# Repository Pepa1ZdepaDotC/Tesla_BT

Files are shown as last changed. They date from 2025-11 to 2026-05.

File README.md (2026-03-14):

# Tesla 1128A repair and BT upgrade

[Schematic](https://github.com/Pepa1ZdepaDotC/Tesla_BT/blob/main/Tesla_rev_2/Tesla_sextant_BT.pdf)





[Interactive BOM](https://htmlpreview.github.io/?https://github.com/Pepa1ZdepaDotC/Tesla_a.s._BT/blob/main/BOM/ibom.html)

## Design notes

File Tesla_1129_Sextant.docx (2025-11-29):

Oprava rádia Tesla 1129 „Sextant“ – Hrubý

FM / AM Rádio není elektronkové, ale tranzistorové, je tam i gramofon. Celkem zachovalé, ovšem zaprášené a též chybí vidlice do zásuvky. Stav elektronických součástek jsem neprověřil, ale na první pohled vypadají v pořádku.

Opravy rádia:

- Výměna a vylepšení feritové (pásek) antény.
- Výměna reproduktoru.
- Oprava / výměna dalších nefunkčních součástek.

Vylepšení funkce:

- NFC čip pro zapnutí rádia mobilem, třeba i bezdrátové nabíjení.
- Bluetooth nebo Wifi připojení.
- Přední panel nastavení rádia.
- Další funkce dle konzultace.

Fotodokumentace:

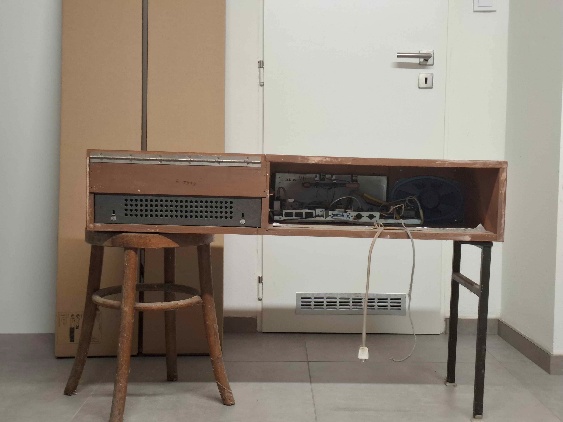
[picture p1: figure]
Obsah obrázku klavír, zeď, interiér, nábytek Popis byl vytvořen automaticky
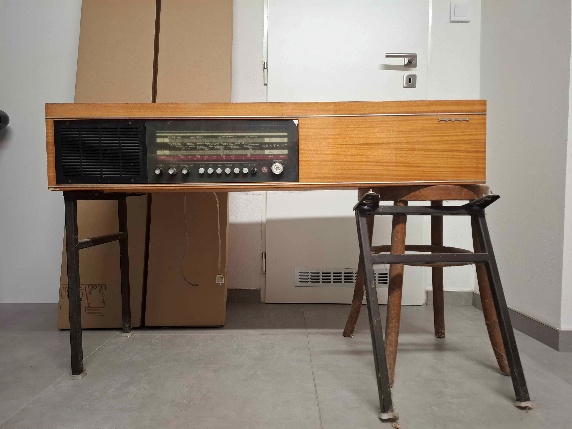
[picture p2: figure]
Obsah obrázku interiér, nábytek, zeď, klavír Popis byl vytvořen automaticky
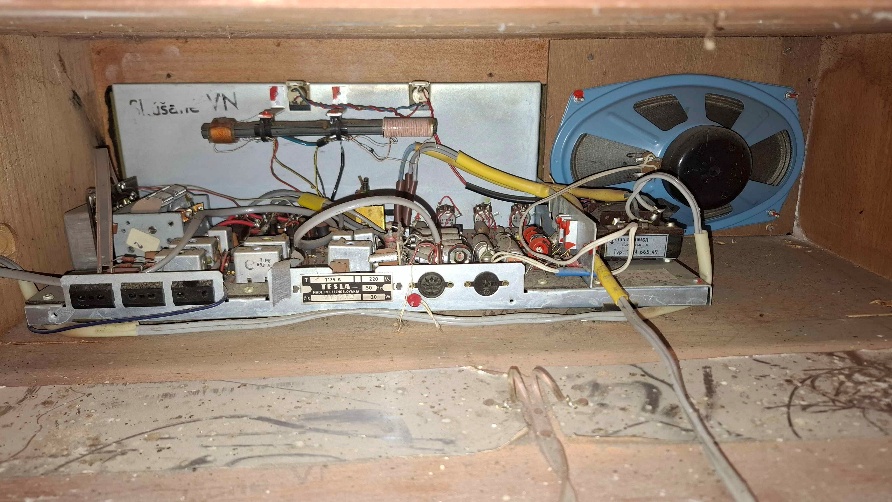
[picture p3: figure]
Obsah obrázku Elektrické vedení, Elektronické inženýrství, obvod, kabel Popis byl vytvořen automaticky

Související odkazy + Technická dokumentace:

https://www.oldradio.cz/ts1129.htm

https://www.oldradio.cz/kottek4/ek1129-30a.pdf

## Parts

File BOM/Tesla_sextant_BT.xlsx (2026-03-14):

Reference | Value | Footprint | Datasheet | Qty | Part_num | DNP | Exclude from BOM | Need | TME | Mouser
C1,C9,C14,C21,C27,C28,C29,C30,C37,C38 | 100nF | Capacitor_SMD:C_0805_2012Metric | ~ | 10
C2,C3,C4,C5,C10,C12,C13,C17,C22,C25,C26 | 10uF | Capacitor_SMD:C_0805_2012Metric | ~ | 11
C6,C7 | 2.2nF | Capacitor_SMD:C_0805_2012Metric | ~ | 2 |  |  |  |  | CL10B222KB8NNNC
C8,C11 | 2.2uF | Capacitor_SMD:C_0805_2012Metric | ~ | 2 |  |  |  | x | CL21B225KAFNNNE
C15,C16 | 470nF | Capacitor_SMD:C_0805_2012Metric | ~ | 2
C23,C24 | 22uF | Capacitor_SMD:C_0805_2012Metric | ~ | 2 |  |  |  | x | CL21A226MAYNNNE
C31 | 5pF | Capacitor_SMD:C_0603_1608Metric | ~ | 1 |  |  |  | x | 06035A5R0CAT2A
C32 | 130pF | Capacitor_SMD:C_0603_1608Metric | ~ | 1 |  |  |  | x | CL10C121JB8NNNC
C33,C40,C42 | 100nF | Capacitor_SMD:C_0603_1608Metric | ~ | 3 |  |  |  | x | 0603B104K500CT
C34,C35 | TBD | Capacitor_SMD:C_0603_1608Metric | ~ | 2 |  |  |  | x
C39 | 44pF | Capacitor_SMD:C_0603_1608Metric | ~ | 1 |  |  |  | x | CC0603BRNPO9BNR47
C41 | TBD | Capacitor_SMD:C_0805_2012Metric | ~ | 1 |  | DNP
D1 | WE-TVS-824015043 | Package_TO_SOT_SMD:SOT-23-6 | https://www.we-online.com/components/products/datasheet/824015043.pdf | 1 |  |  |  | x |  | 824015043
D2 | SMAJ5.0CA | Diode_SMD:D_SMA | https://www.littelfuse.com/media?itemid=75e32973-b177-4ee3-a0ff-cedaf1abdb93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 | 1 |  |  |  | x |  | SMAJ5.0CA
D3,D4,D6 | B240 | Diode_SMD:D_SMB | http://www.jameco.com/Jameco/Products/ProdDS/1538777.pdf | 3 |  |  |  | x |  | B240
D5 | SMAJ36A | Diode_SMD:D_SMA | https://www.littelfuse.com/media?itemid=75e32973-b177-4ee3-a0ff-cedaf1abdb93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 | 1 |  |  |  | x |  | SMAJ36A
D7,D8 | SMAJ5.0A | Diode_SMD:D_SMA | https://www.littelfuse.com/media?itemid=75e32973-b177-4ee3-a0ff-cedaf1abdb93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 | 2 |  |  |  | x |  | SMAJ5.0A
J1,J3 | Conn_01x05 | Connector_PinSocket_2.00mm:PinSocket_1x05_P2.00mm_Vertical | ~ | 2 |  |  |  | x |  | 831-87-005-10-001101
J6 | USB_C_Receptacle_USB2.0_16P | Connector_USB:USB_C_Receptacle_GCT_USB4105-xx-A_16P_TopMnt_Horizontal | https://www.usb.org/sites/default/files/documents/usb_type-c.zip | 1 | USB4105-GF-A |  |  | x | USB4105-GF-A
K1 | G6EU | Relay_THT:Relay_SPDT_Omron_G6E | https://www.omron.com/ecb/products/pdf/en-g6e.pdf | 1 |  |  |  | x | G6EU-134P-US-5DC
L2 | 2.2uH | Inductor_SMD:L_12x12mm_H8mm | https://www.eaton.com/content/dam/eaton/products/electronic-components/resources/data-sheet/eaton-dr-high-power-density-high-efficiency-shielded-drum-core-pow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 | 1 | DR125-2R2-R |  |  | x | DR125-2R2-R
L3 | 1uH | Capacitor_SMD:C_0603_1608Metric_Pad1.08x0.95mm_HandSolder | ~ | 1 |  |  |  | x | MLZ1608A1R0WT
L4 | 40nH | Capacitor_SMD:C_0603_1608Metric_Pad1.08x0.95mm_HandSolder | ~ | 1 |  |  |  |  | LQW18AN39NG00D
L5 | TBD | Inductor_SMD:L_0603_1608Metric | ~ | 1
L6,L7 | MABAES0060 | Tesla_Library:SM-22 | https://cdn.macom.com/datasheets/MABAES0060.pdf | 2 |  |  |  | x |  | MABAES0060
L8 | 900nH | Inductor_SMD:L_0603_1608Metric | ~ | 1 |  |  |  | x | NL03JTCR82
Q1 | BC817 | Package_TO_SOT_SMD:SOT-23 | https://www.onsemi.com/pub/Collateral/BC818-D.pdf | 1
R1,R2,R3,R6,R7,R16 | 10K | Resistor_SMD:R_0805_2012Metric | ~ | 6
R8,R10 | 470 | Resistor_SMD:R_0805_2012Metric | ~ | 2 |  |  |  | x | ERJHP6D4700V
R9,R11 | 3.3K | Resistor_SMD:R_0805_2012Metric | ~ | 2
R12,R13 | TBD | Resistor_SMD:R_0805_2012Metric | ~ | 2 |  |  |  | x
R14 | 7.5K | Resistor_SMD:R_0805_2012Metric | ~ | 1
R15,R17 | 1K | Resistor_SMD:R_0805_2012Metric | ~ | 2
R19,R20 | 100K | Resistor_SMD:R_0805_2012Metric | ~ | 2
R22,R23 | 5.1K | Resistor_SMD:R_0805_2012Metric | ~ | 2
R25 | 120 | Resistor_SMD:R_0805_2012Metric | ~ | 1 |  |  |  | x | WR08X1200FTL
R26 | 820 | Resistor_SMD:R_0805_2012Metric | ~ | 1 |  |  |  | x | ERA6AEB821V
R27,R33,R34 | 75 | Resistor_SMD:R_0805_2012Metric | ~ | 3 |  |  |  | x | RC0805FR-0775RL
R28 | 100 | Resistor_SMD:R_0805_2012Metric | ~ | 1 |  |  |  | x | RCA0805100RFKEA
R30 | 50 | Resistor_SMD:R_0805_2012Metric | ~ | 1 |  |  |  | x | CRCW080549R9FKE
R31,R32 | 5K | Resistor_SMD:R_0805_2012Metric | ~ | 2
U1 | ESP32-C3-WROOM-02 | RF_Module:ESP32-C3-WROOM-02 | https://www.espressif.com/sites/default/files/documentation/esp32-c3-wroom-02_datasheet_en.pdf | 1 |  |  |  | x |  | ESP32-C3-WROOM-02-N4
U2 | PCM5102A | Package_SO:TSSOP-20_4.4x6.5mm_P0.65mm | https://www.ti.com/lit/ds/symlink/pcm5102a.pdf | 1 |  |  |  | x |  | PCM5102APWR
U3 | OPA2342 | Package_SO:SOIC-8_3.9x4.9mm_P1.27mm | https://www.ti.com/lit/gpn/opa2342 | 1 |  |  |  | x |  | OPA2342
U4 | TPA0211 | Package_SO:HVSSOP-8-1EP_3x3mm_P0.65mm_EP1.57x1.89mm_ThermalVias | https://www.ti.com/lit/gpn/tpa0211 | 1 |  |  |  | x |  | TPA0211DGN
U5 | USBLC6-2SC6 | Package_TO_SOT_SMD:SOT-23-6 | https://www.st.com/resource/en/datasheet/usblc6-2.pdf | 1 |  |  |  | x |  | USBLC6-2SC6
U6 | AP63203WU | Package_TO_SOT_SMD:TSOT-23-6 | https://www.diodes.com/assets/Datasheets/AP63200-AP63201-AP63203-AP63205.pdf | 1 |  |  |  | x |  | AP63203WU-7
U7 | LD1117STR | Package_TO_SOT_SMD:SOT-223 |  | 1 |  |  |  | x |  | LD1117STR
U8 | AD831 | Package_LCC:PLCC-20 | https://www.analog.com/en/products/ad831.html?doc=ad831.pdf | 1 |  |  |  | x |  | AD831
Y1 | OSC25M-3.3I/S5 | Oscillator:Oscillator_SMD_Fordahl_DFAS15-4Pin_5.0x3.2mm_HandSoldering | https://www.tme.eu/Document/7a0ceeaed569e73bfa5cc28fb0e463dd/YIC-S7.pdf | 1 |  |  |  | x | OSC25M-3.3I/S5
 |  |  |  |  |  |  |  |  | 20 | 15

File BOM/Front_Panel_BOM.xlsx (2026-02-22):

Reference | Qty | Value | DNP | Exclude from BOM | Exclude from Board | Footprint | Datasheet
C1,C2,C3,C4 | 4 | 470nF |  |  |  | Capacitor_SMD:C_0805_2012Metric | ~
C5,C6,C7 | 3 | 100nF |  |  |  | Capacitor_SMD:C_0805_2012Metric | ~
H1,H2,H3,H4 | 4 | MountingHole_Pad |  | Excluded from BOM |  | MountingHole:MountingHole_4.3mm_M4_DIN965_Pad_TopBottom | ~
J1 | 1 | Conn_01x05 |  |  |  | Connector_PinSocket_2.00mm:PinSocket_1x05_P2.00mm_Vertical | ~
J2 | 1 | Conn_01x05 | DNP |  |  | Connector_PinSocket_2.00mm:PinSocket_1x05_P2.00mm_Vertical | ~
Q1 | 1 | BC817 |  |  |  | Package_TO_SOT_SMD:SOT-23 | https://www.onsemi.com/pub/Collateral/BC818-D.pdf
R1 | 1 | 0R | DNP |  |  | Resistor_SMD:R_0805_2012Metric | ~
R2 | 1 | 1K |  |  |  | Resistor_SMD:R_0805_2012Metric | ~
R3,R4,R5,R6 | 4 | 10K |  |  |  | Resistor_SMD:R_0805_2012Metric | ~
SW1,SW2,SW3,SW4 | 4 | SW_Push |  |  |  | Button_Switch_THT:SW_PUSH-12mm_Wuerth-430476085716 | ~
TP1,TP2 | 2 | TestPoint |  |  |  | TestPoint:TestPoint_Pad_D3.0mm | ~
U1 | 1 | NHD-C0220BIZ |  |  |  | Display:NHD-C0220BiZ | http://www.newhavendisplay.com/specs/NHD-C0220BiZ-FSW-FBW-3V3M.pdf
U2 | 1 | MCP23008-xSO |  |  |  | Package_SO:SOIC-18W_7.5x11.6mm_P1.27mm | http://ww1.microchip.com/downloads/en/DeviceDoc/MCP23008-MCP23S08-Data-Sheet-20001919F.pdf

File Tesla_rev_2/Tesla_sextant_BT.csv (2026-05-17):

Reference | Value | Qty | Part_num
C1,C9,C21,C27,C28,C29,C30,C37,C38 | 100nF | 9
C2,C3,C4,C5,C10,C12,C13,C22,C25,C26 | 10uF | 10
C6,C7 | 2.2nF | 2
C8,C11 | 2.2uF | 2
C15,C16 | 470nF | 2
C23,C24 | 22uF | 2
C31,C34,C35 | 5pF | 3
C32 | 130pF | 1
C33,C40,C42 | 100nF | 3
C36 | 510pF | 1
C39 | 44pF | 1
C41 | TBD | 1
D1 | WE-TVS-824015043 | 1
D2 | SMAJ5.0CA | 1
D3,D4,D6 | B240 | 3
D5 | SMAJ36A | 1
D7,D8 | SMAJ5.0A | 2
J1,J3 | Conn_01x05 | 2
J6 | USB_C_Receptacle_USB2.0_16P | 1 | USB4105-GF-A
K1 | G5V-1 | 1
L2 | 2.2uH | 1 | DR125-2R2-R
L3 | 1uH | 1
L4 | 40nH | 1
L5 | 430nH | 1
L6,L7 | MABAES0060 | 2
L8 | 900nH | 1
Q1 | BC817 | 1
R1,R2,R3,R6,R7,R16 | 10K | 6
R8,R10 | 470 | 2
R9,R11 | 3.3K | 2
R12,R13 | TBD | 2
R15 | 1K | 1
R22,R23 | 5.1K | 2
R25 | 120 | 1
R26 | 820 | 1
R27,R33,R34 | 75 | 3
R28 | 100 | 1
R29 | 200 | 1
R30 | 50 | 1
R31,R32 | 5K | 2
U1 | ESP32-C3-WROOM-02 | 1
U2 | PCM5102A | 1
U4 | TPA0211 | 1
U5 | USBLC6-2SC6 | 1
U6 | AP63203WU | 1
U7 | LD1117STR | 1
U8 | AD831 | 1
Y1 | OSC25M-3.3I/S5 | 1
C1,C2,C3,C4 | 470nF | 4
C5,C6,C7 | 100nF | 3
J1 | Conn_01x05 | 1
J2 | Conn_01x05 | 1
Q1 | BC817 | 1
R1 | 0R | 1
R2 | 1K | 1
R3,R4,R5,R6 | 10K | 4
SW1,SW2,SW3,SW4 | SW_Push | 4
TP1,TP2 | TestPoint | 2
U1 | NHD-C0220BIZ | 1
U2 | MCP23008-xSO | 1

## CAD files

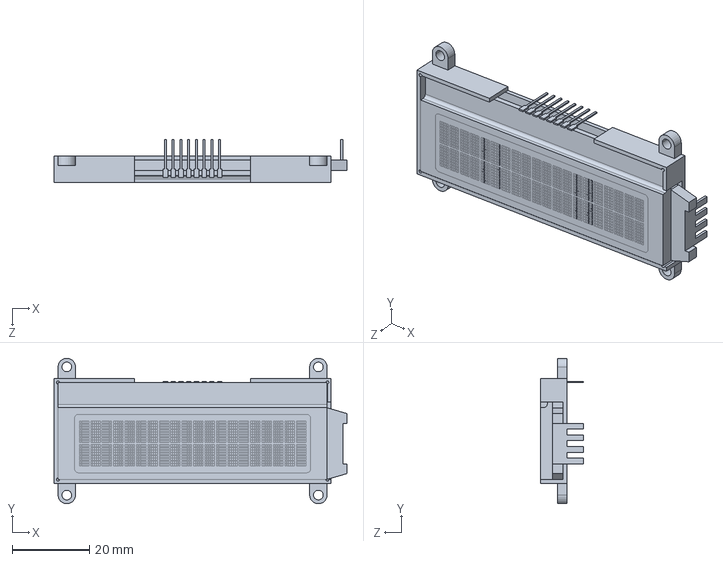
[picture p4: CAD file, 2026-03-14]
Front_Panel/verified_NHD-C0220BiZ-FSRGB-FBW-3VM.STEP
75.7 x 37.6 x 11.0 mm

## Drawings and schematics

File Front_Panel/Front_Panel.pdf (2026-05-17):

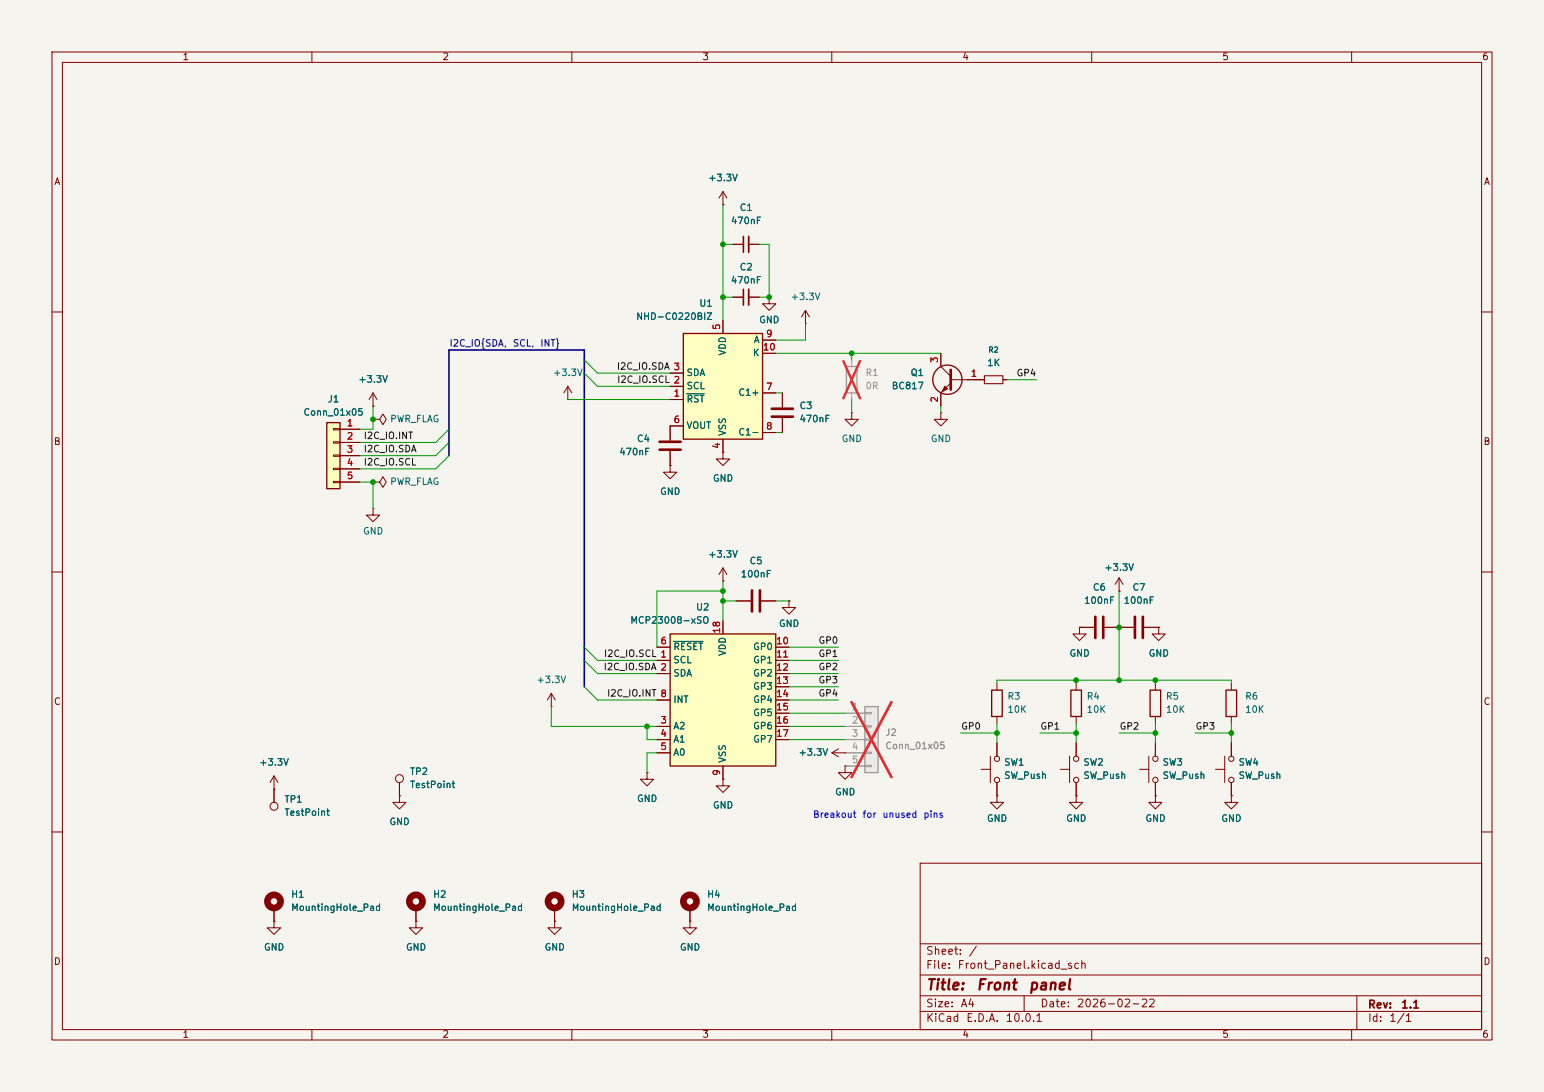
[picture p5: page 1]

Size: A4 | Rev: 1.1
KiCad E.D.A. 10.0.1 | Id: 1/1

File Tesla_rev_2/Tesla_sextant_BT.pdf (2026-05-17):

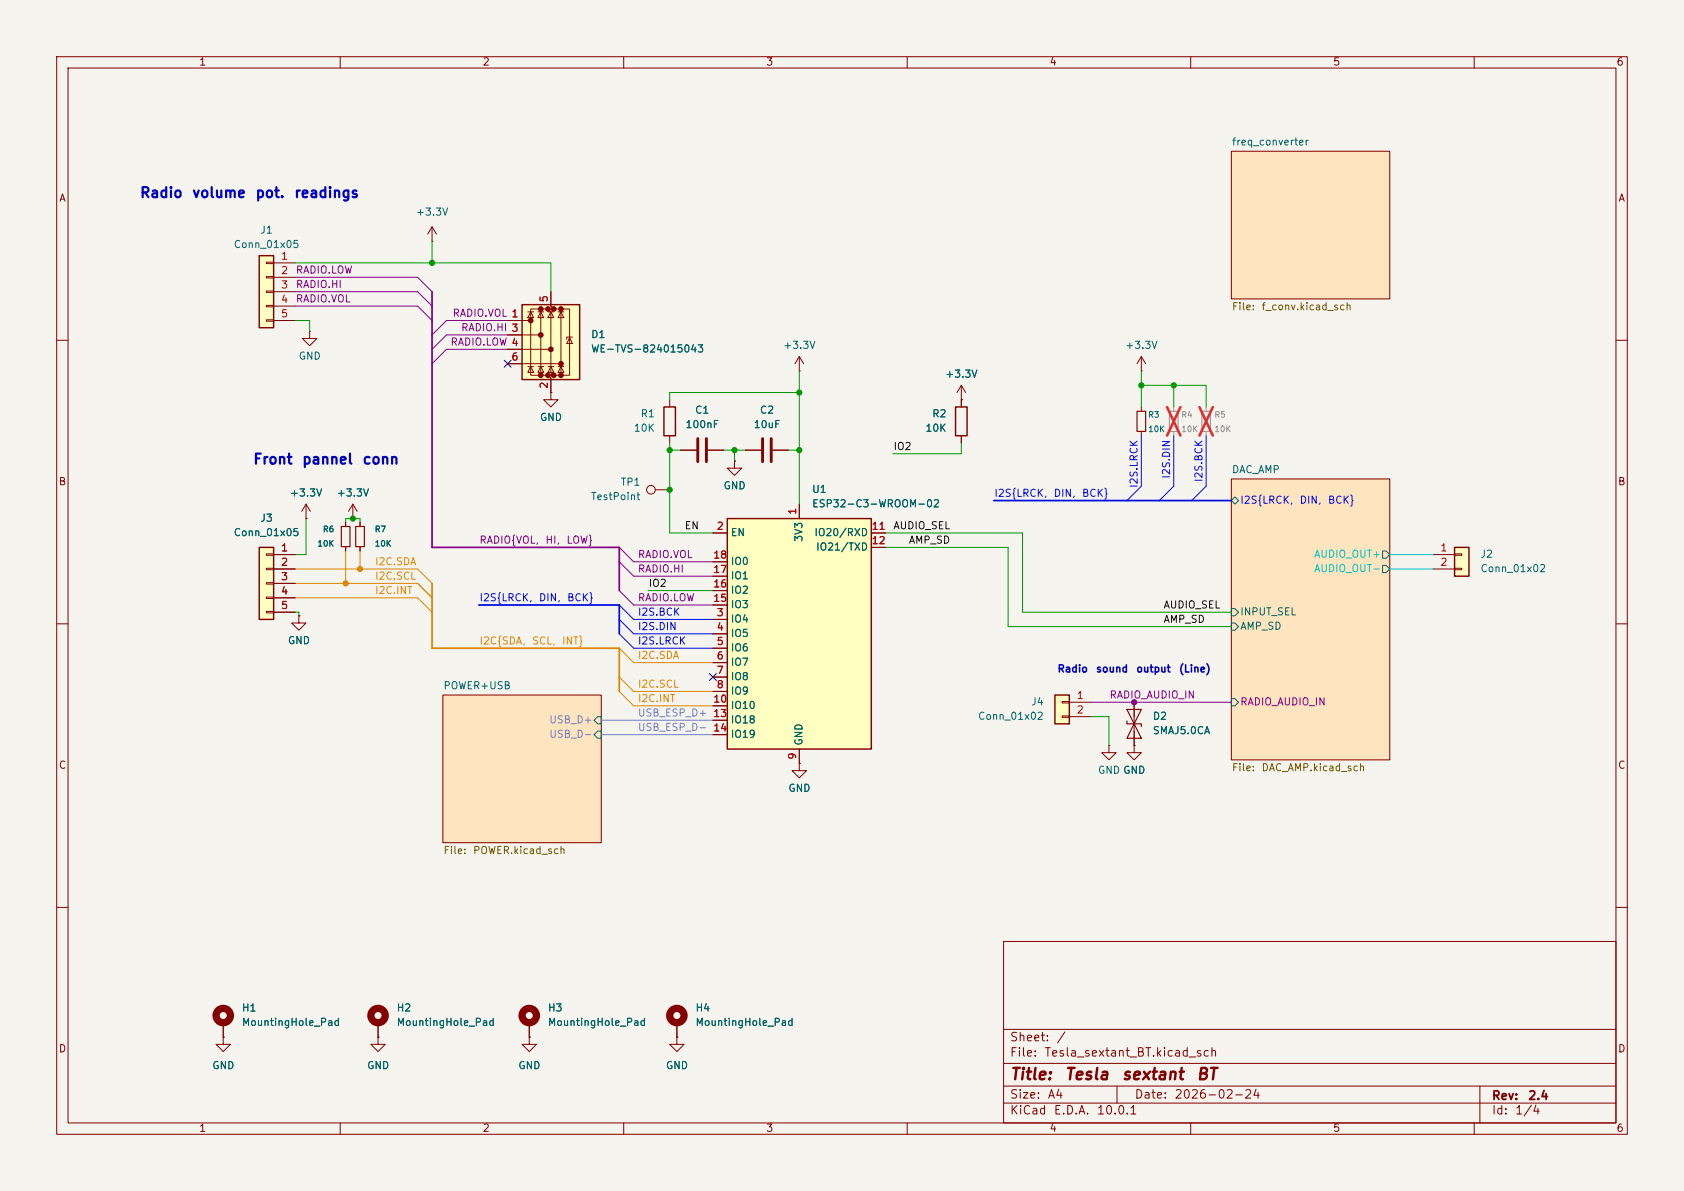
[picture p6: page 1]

I2S.BCK Front pannel conn Radio volume pot. readings

Radio sound output (Line) C2

Sheet: /
File: Tesla_sextant_BT.kicad_sch
Title: Tesla sextant BT

Size: A4 | Rev: 2.4
KiCad E.D.A. 10.0.1 | Id: 1/4

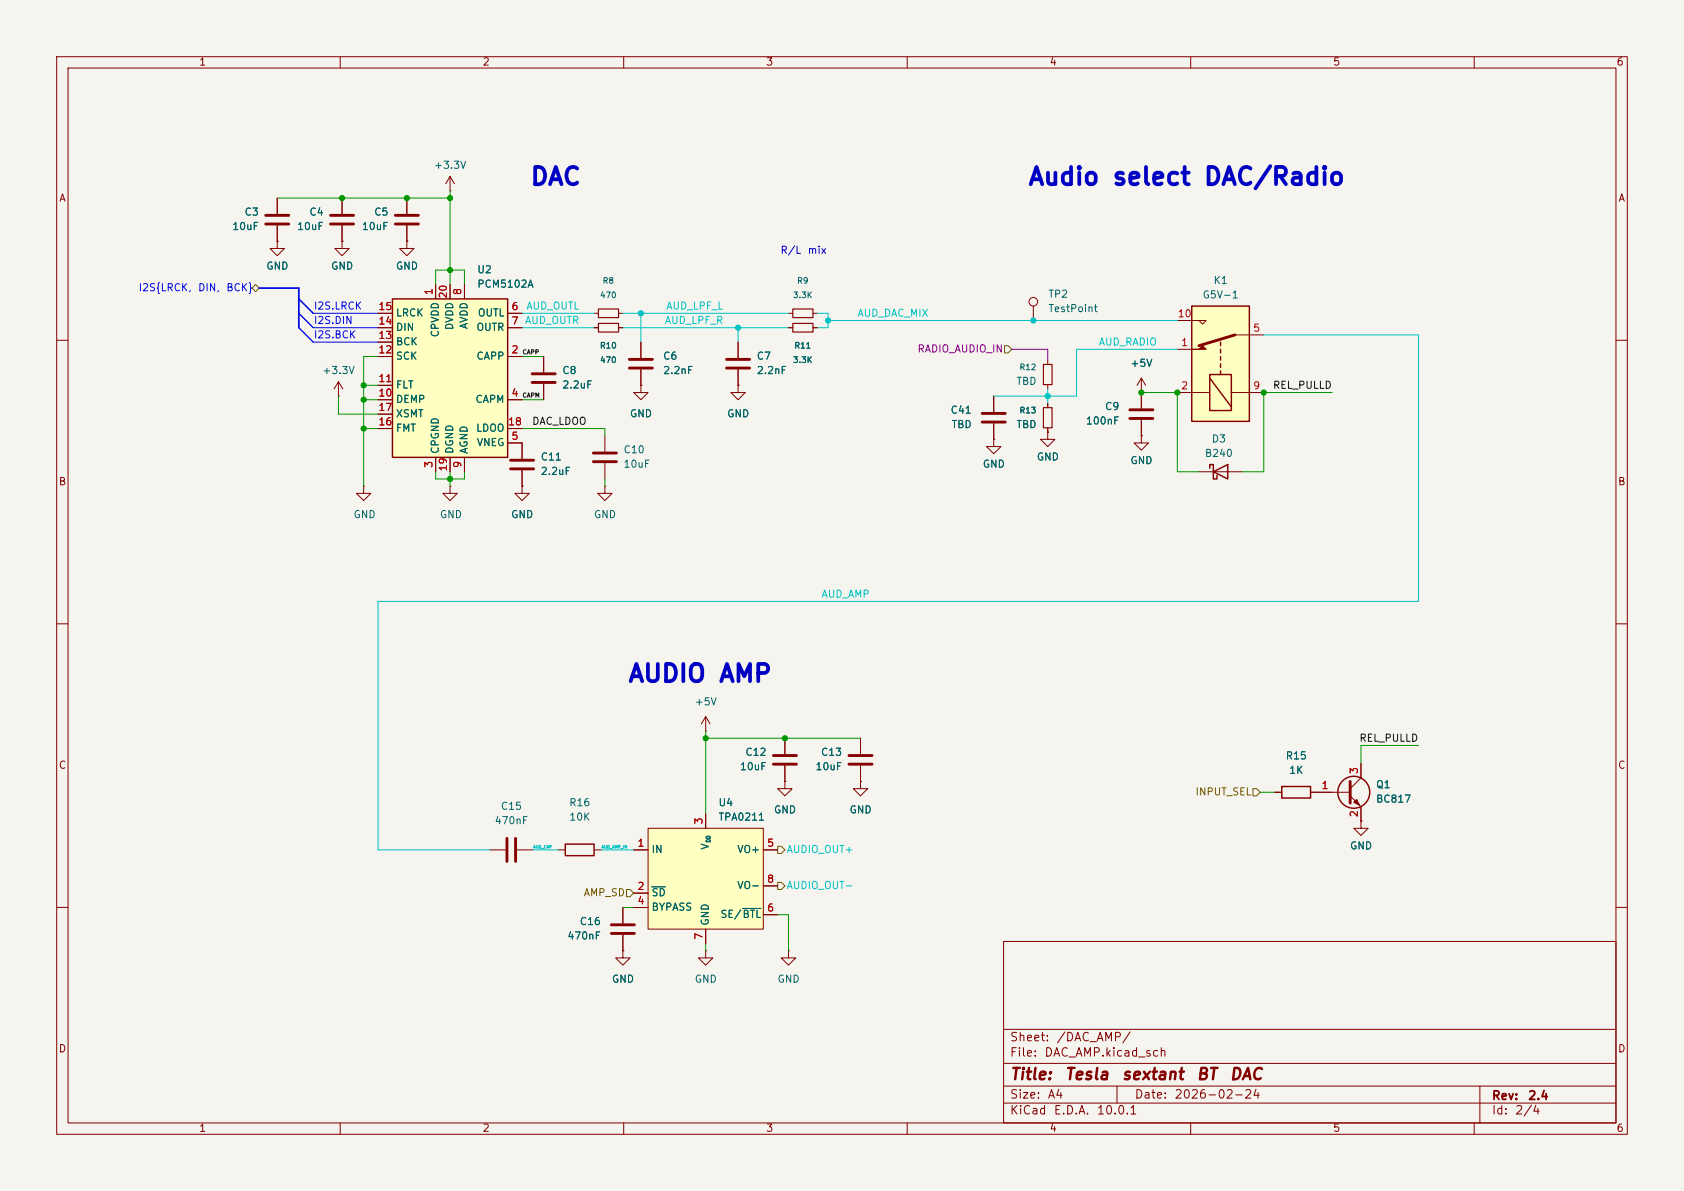
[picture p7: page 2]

SCK 12 BCK 13 DIN 14 LRCK 15

Sheet: /DAC_AMP/
File: DAC_AMP.kicad_sch
Title: Tesla sextant BT DAC

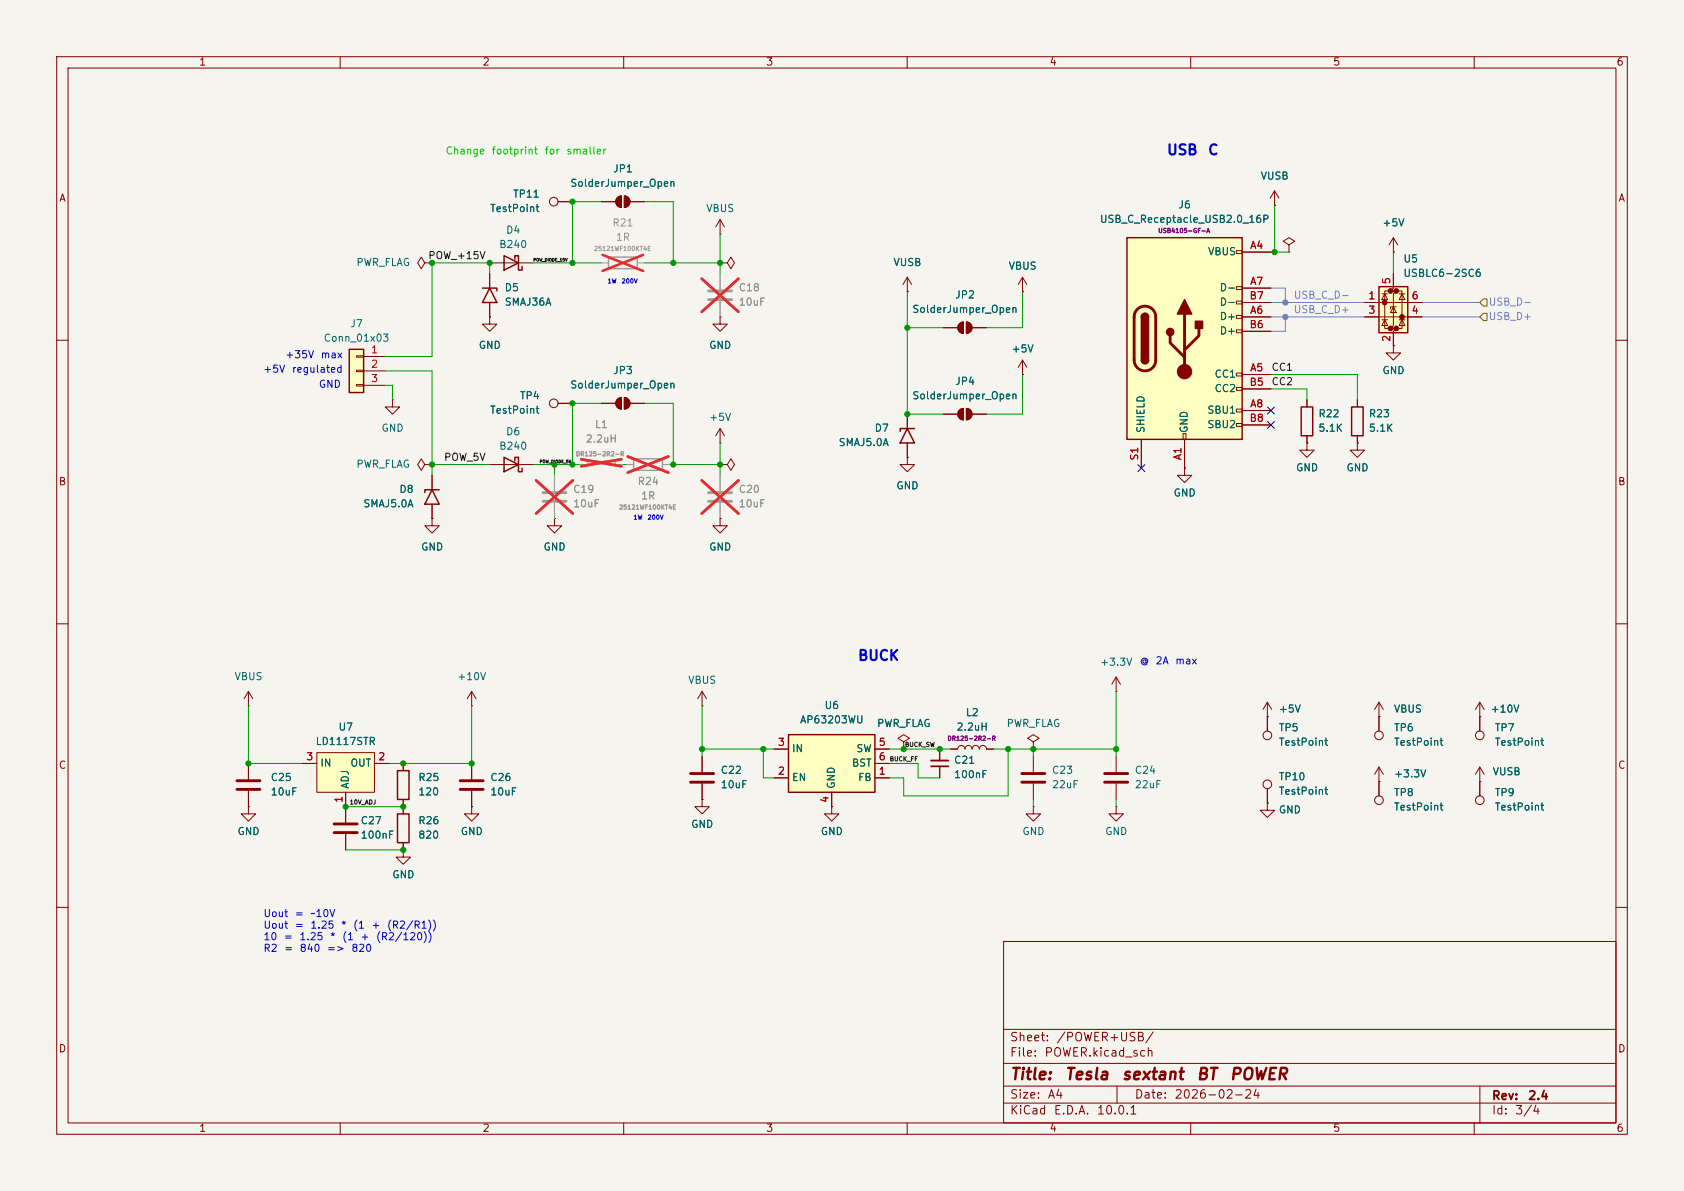
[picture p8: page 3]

Change footprint for smaller Uout = ~10V Uout = 1.25 * (1 + (R2/R1)) 10 = 1.25 * (1 + (R2/120)) R2 = 840 => 820 +35V max +5V regulated GND

File: POWER.kicad_sch
Title: Tesla sextant BT POWER

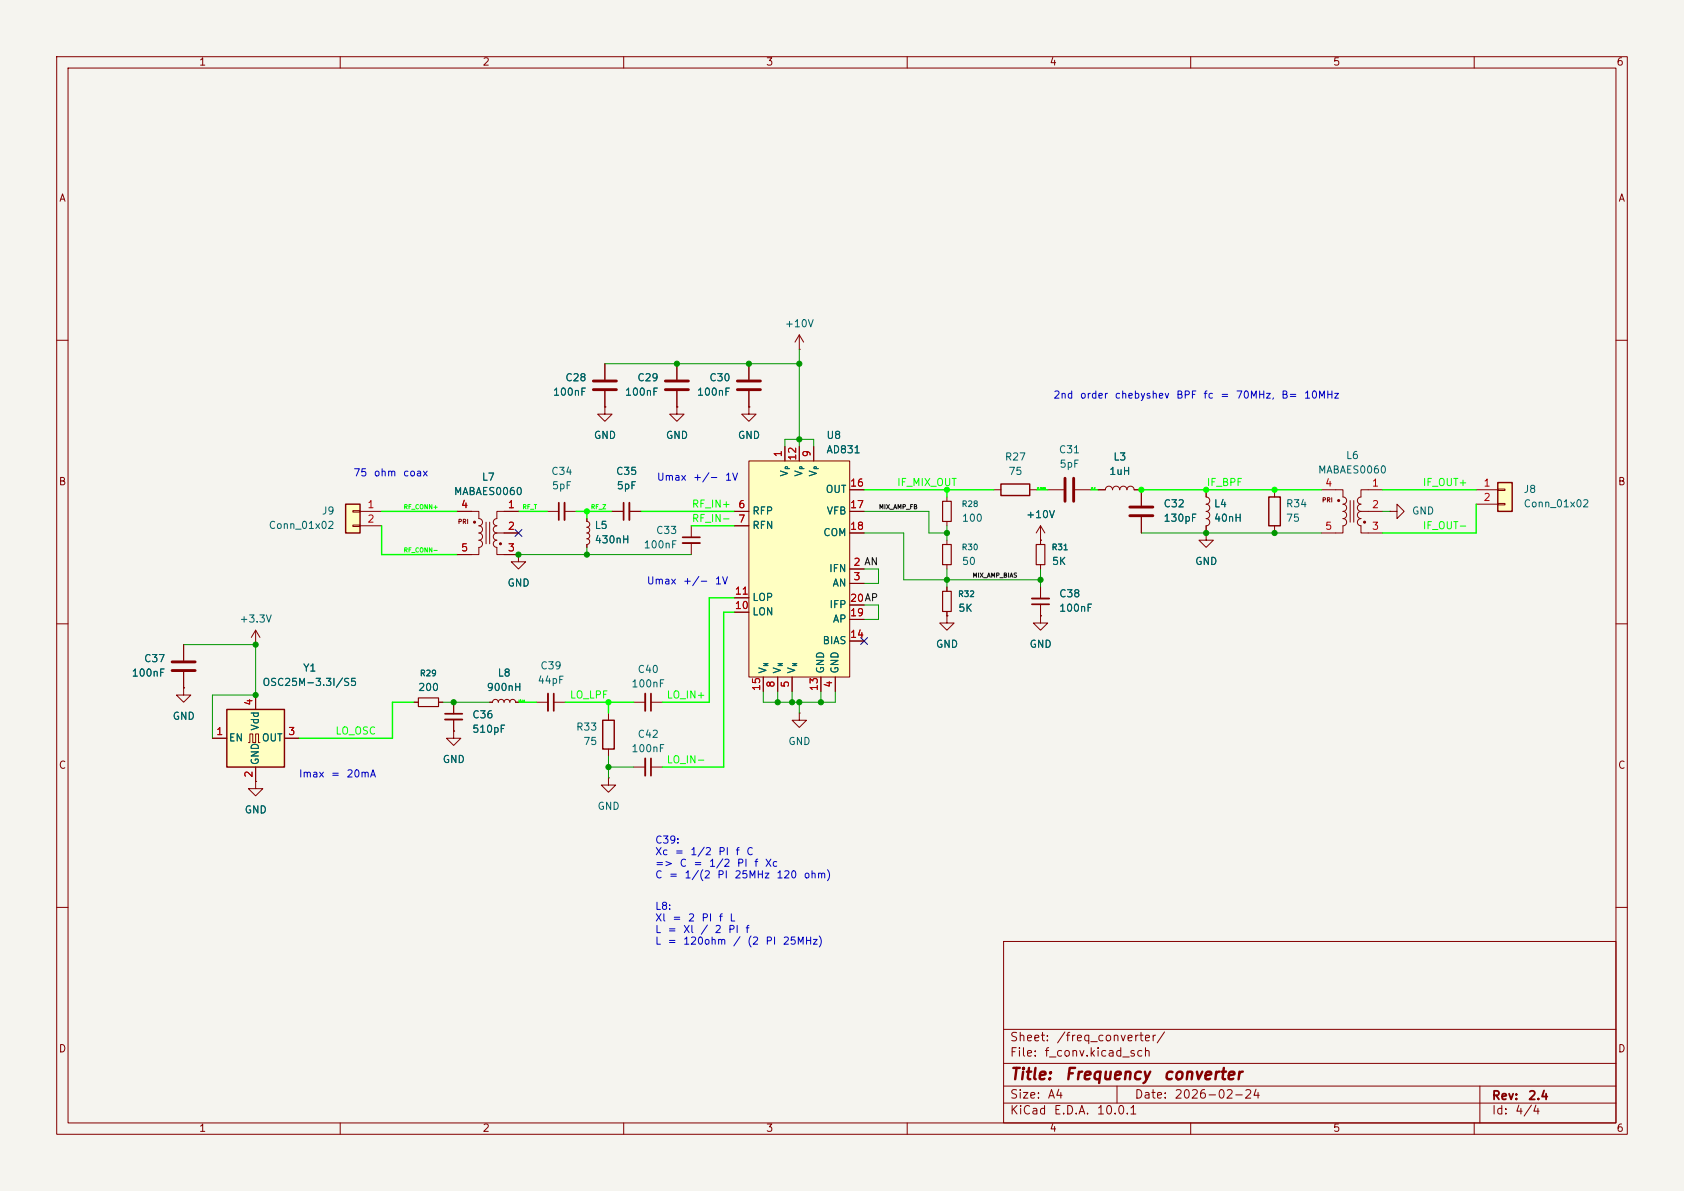
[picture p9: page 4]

2nd order chebyshev BPF fc = 70MHz, B= 10MHz

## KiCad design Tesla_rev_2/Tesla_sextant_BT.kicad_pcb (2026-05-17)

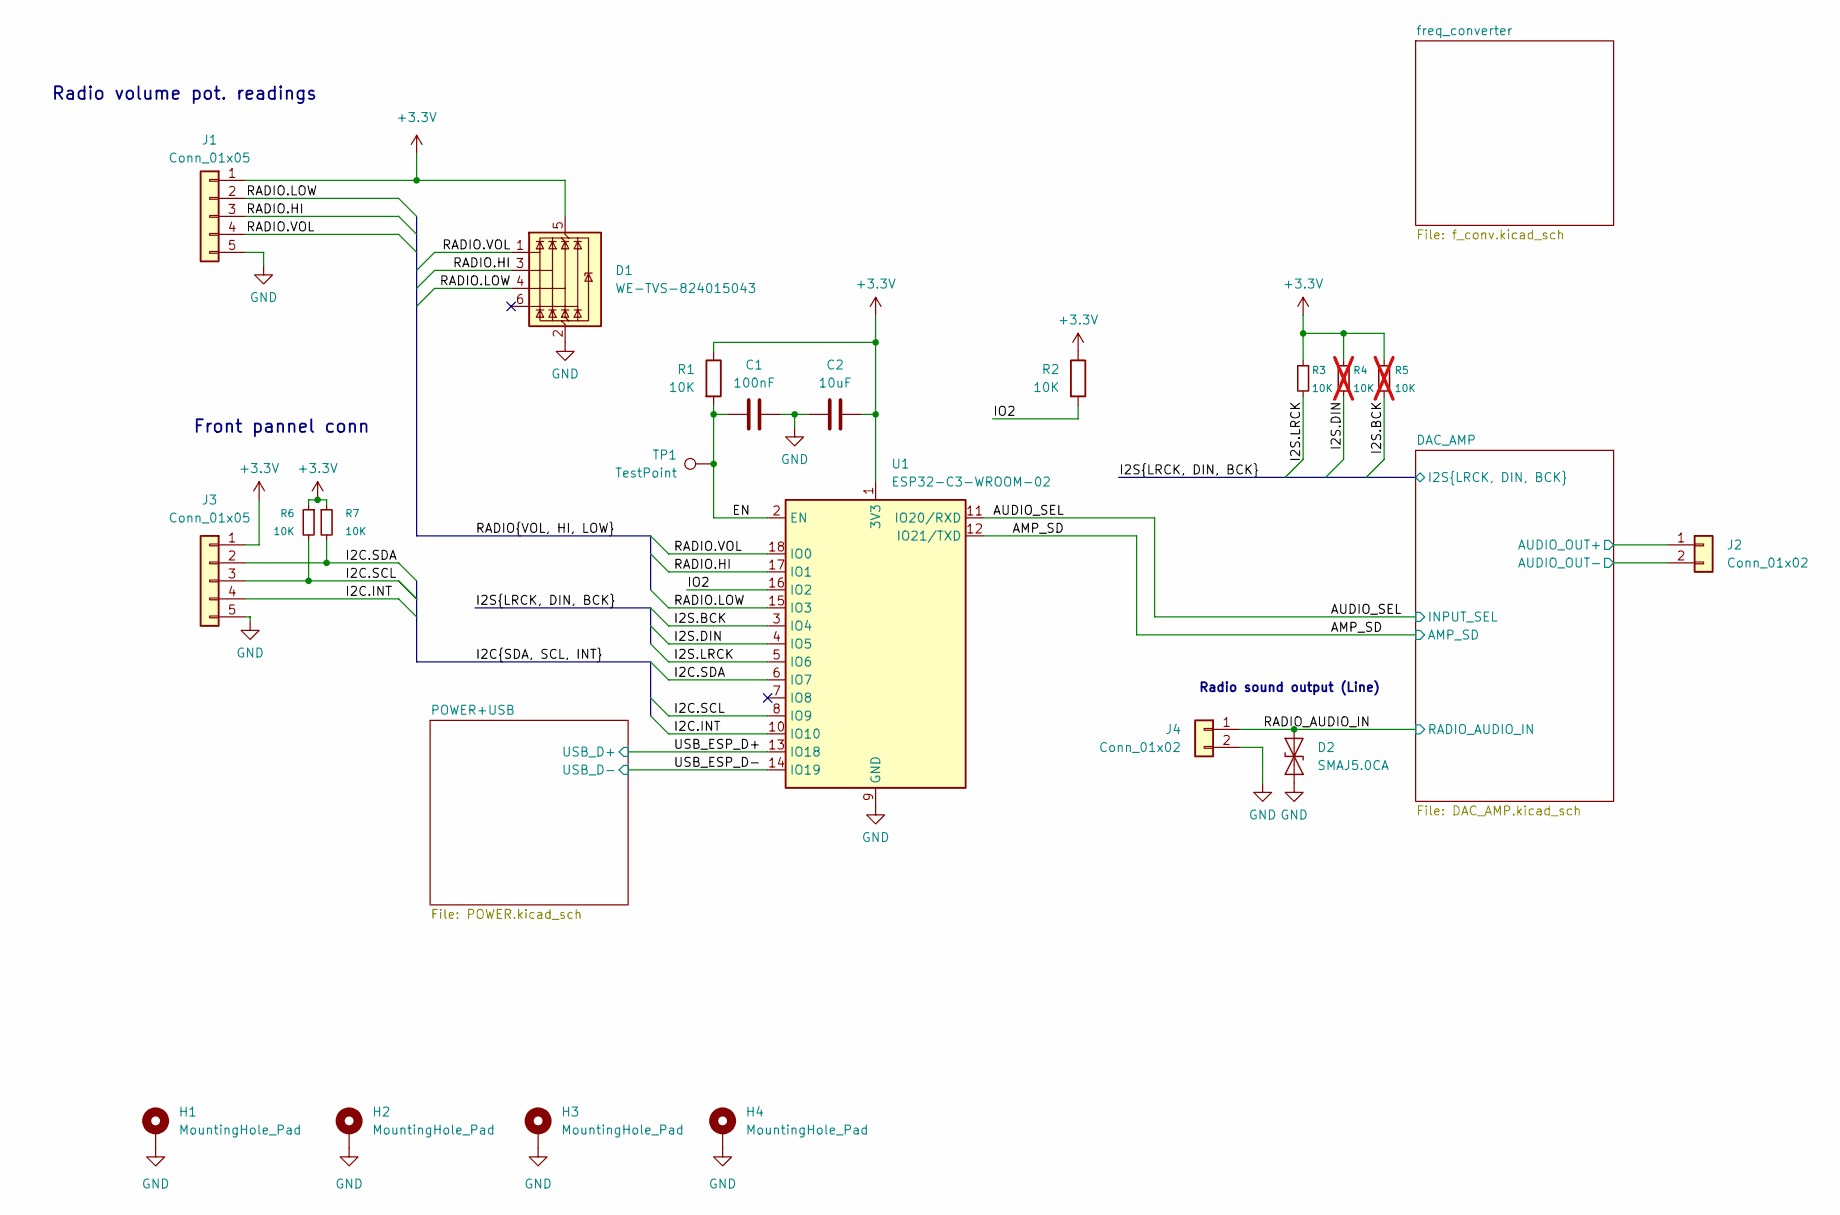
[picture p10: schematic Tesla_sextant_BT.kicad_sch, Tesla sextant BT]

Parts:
C1: 100nF; C_0805_2012Metric
C2: 10uF; C_0805_2012Metric
D1: WE-TVS-824015043; SOT-23-6
D2: SMAJ5.0CA; D_SMA
H1, H2, H3, H4: MountingHole_Pad; MountingHole_4.3mm_M4_DIN965_Pad_TopBottom
J1, J3: Conn_01x05; PinSocket_1x05_P2.00mm_Vertical
J2, J4: Conn_01x02; Conn_Solder_1x02_SMD
R1, R2, R3, R6, R7: 10K; R_0805_2012Metric
R4, R5: 10K; R_0805_2012Metric; not fitted
TP1: TestPoint; TestPoint_Pad_D2.5mm
U1: ESP32-C3-WROOM-02

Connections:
+3.3V: C2.1, D1.5 (VBUS), J1.1, J3.1, R1.1, R2.1, R3.1, R4.1, R5.1, R6.1, R7.1, U1.1 (3V3); also elsewhere on the board
/AMP_SD: U1.12 (IO21/TXD); also elsewhere on the board
/AUDIO_SEL: U1.11 (IO20/RXD); also elsewhere on the board
/DAC_AMP/AUDIO_OUT+: J2.1; also elsewhere on the board
/DAC_AMP/AUDIO_OUT-: J2.2; also elsewhere on the board
/EN: C1.2, R1.2, TP1.1, U1.2 (EN)
/I2C.INT: J3.4, U1.10 (IO10)
/I2C.SCL: J3.3, R6.2, U1.8 (IO9)
/I2C.SDA: J3.2, R7.2, U1.6 (IO7)
/I2S.BCK: R5.2, U1.3 (IO4); also elsewhere on the board
/I2S.DIN: R4.2, U1.4 (IO5); also elsewhere on the board
/I2S.LRCK: R3.2, U1.5 (IO6); also elsewhere on the board
/IO2: R2.2, U1.16 (IO2)
/RADIO.HI: D1.3 (I/O2), J1.3, U1.17 (IO1)
/RADIO.LOW: D1.4 (I/O3), J1.2, U1.15 (IO3)
/RADIO.VOL: D1.1 (I/O1), J1.4, U1.18 (IO0)
/RADIO_AUDIO_IN: D2.1 (A1), J4.1; also elsewhere on the board
/USB_ESP_D+: U1.13 (IO18); also elsewhere on the board
/USB_ESP_D-: U1.14 (IO19); also elsewhere on the board
GND: C1.1, C2.2, D1.2 (GND), D2.2 (A2), H1.1, H2.1, H3.1, H4.1, J1.5, J3.5, J4.2, U1.9 (GND), U1.19 (GND); also elsewhere on the board

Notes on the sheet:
Radio volume pot. readings
Radio sound output (Line)
Front pannel conn

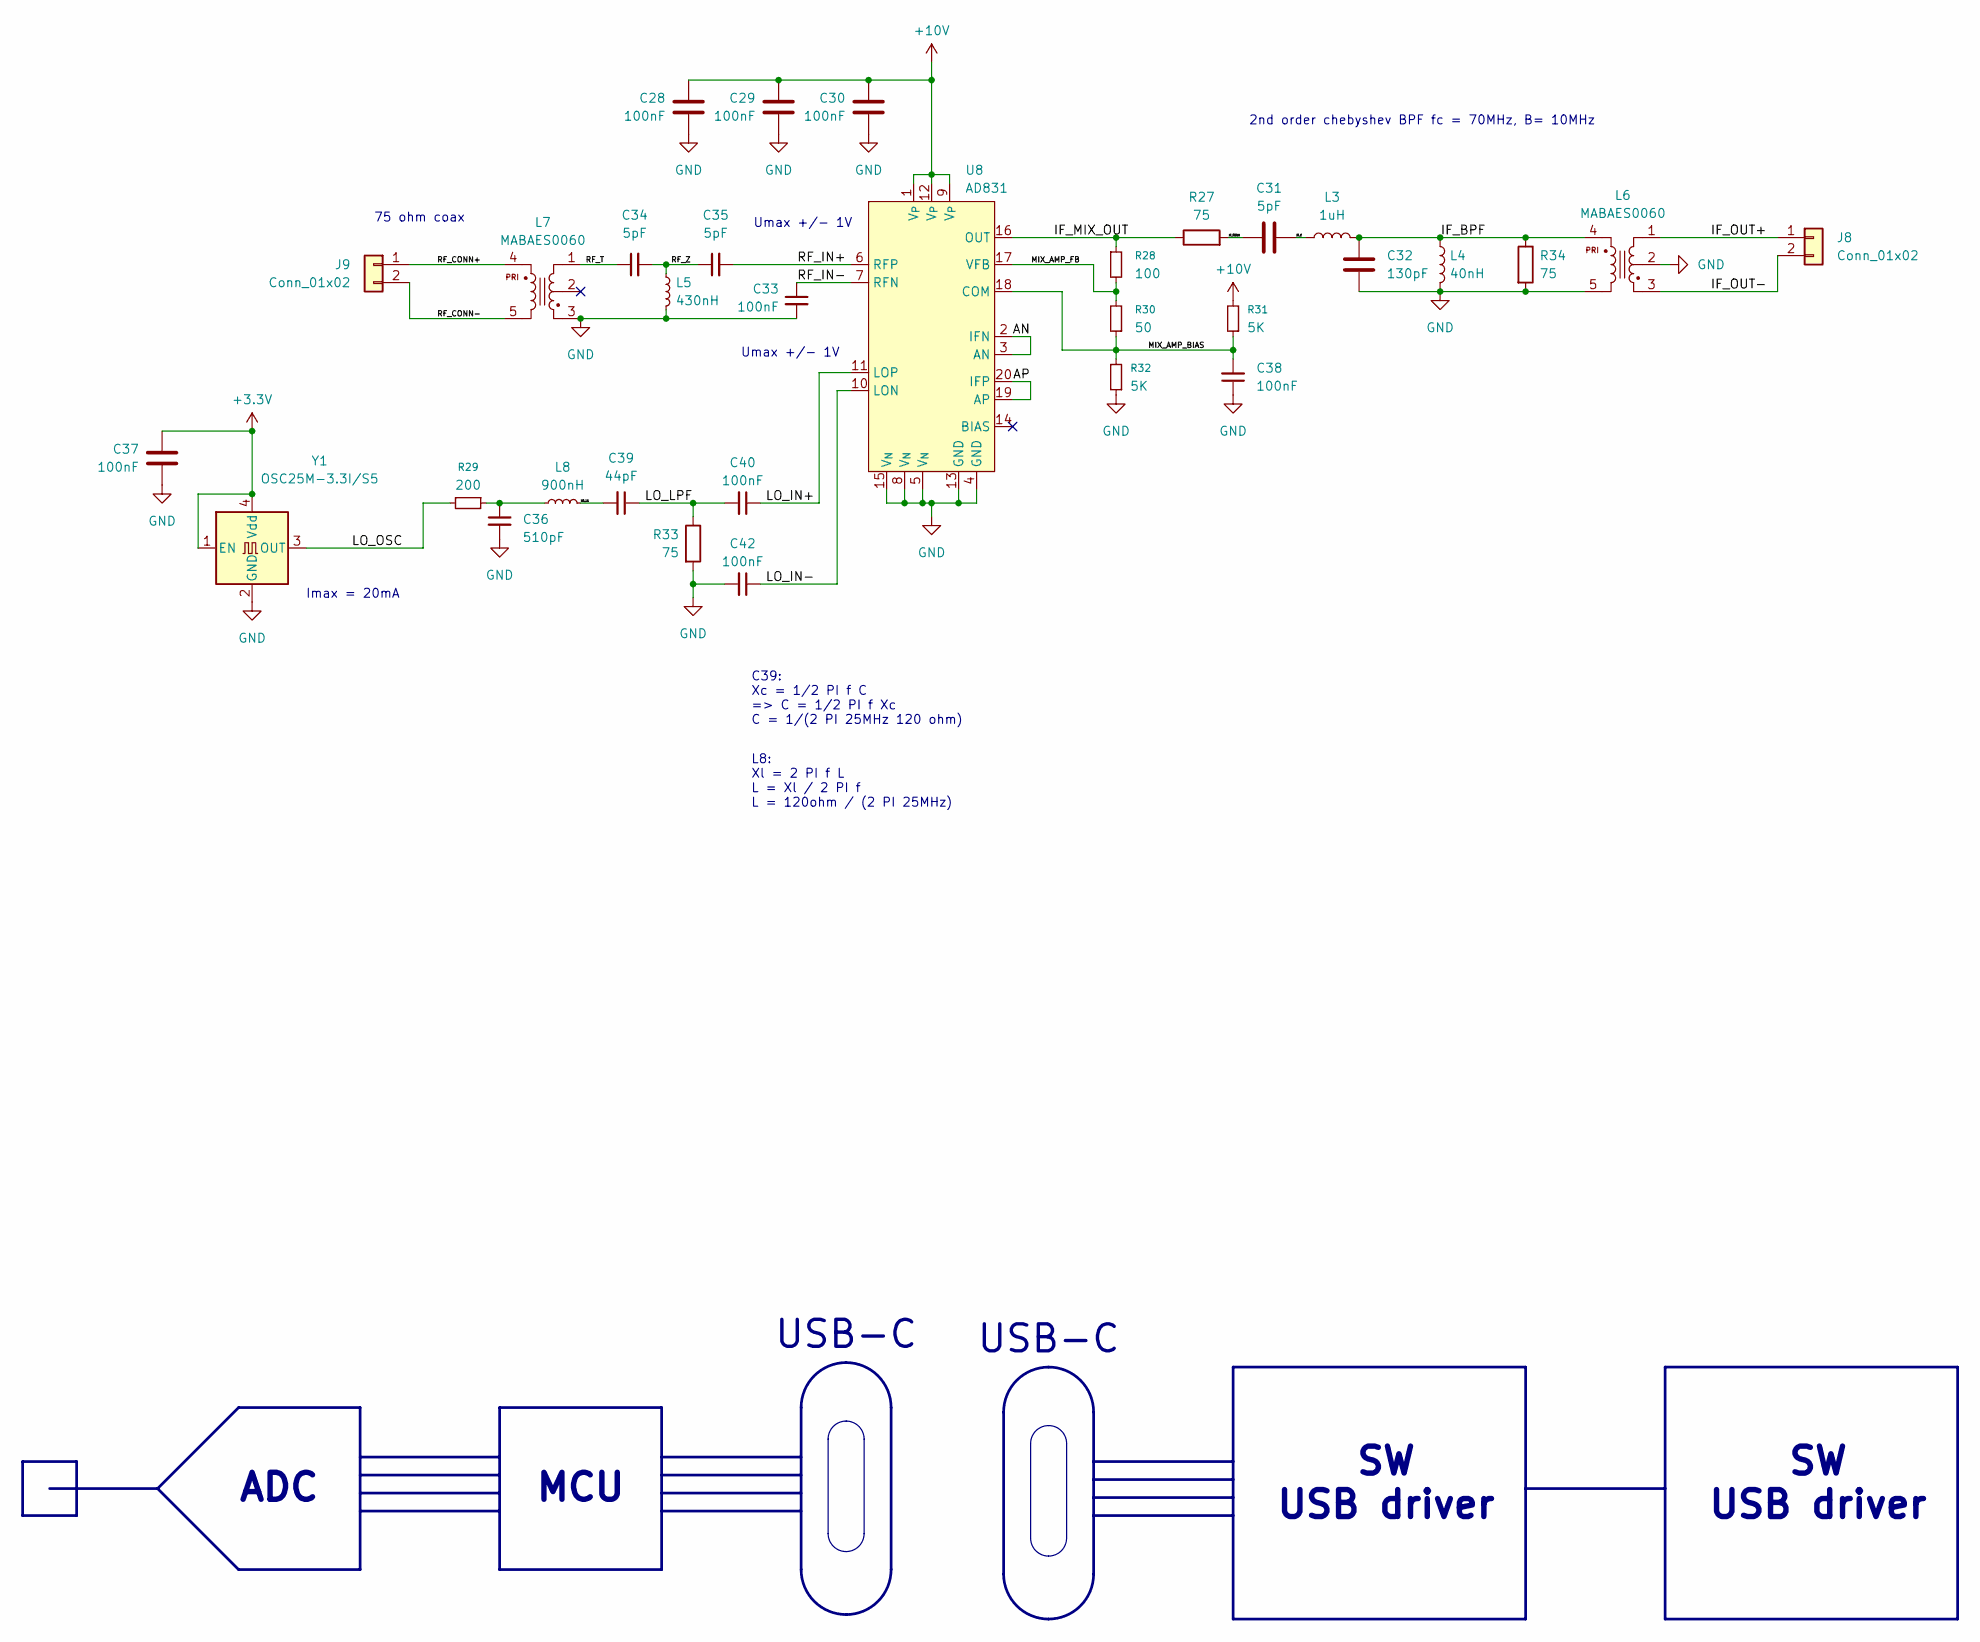
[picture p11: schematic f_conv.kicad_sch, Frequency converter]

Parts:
C28, C29, C30, C37, C38: 100nF; C_0805_2012Metric
C31, C34, C35: 5pF; C_0603_1608Metric
C32: 130pF; C_0603_1608Metric
C33, C40, C42: 100nF; C_0603_1608Metric
C36: 510pF; C_0603_1608Metric
C39: 44pF; C_0603_1608Metric
J8, J9: Conn_01x02; Conn_Solder_1x02_SMD
L3: 1uH; L_0603_1608Metric
L4: 40nH; L_0603_1608Metric
L5: 430nH; L_0603_1608Metric
L6, L7: MABAES0060; SM-22
L8: 900nH; L_0603_1608Metric
R27, R33, R34: 75; R_0805_2012Metric
R28: 100; R_0805_2012Metric
R29: 200; R_0805_2012Metric
R30: 50; R_0805_2012Metric
R31, R32: 5K; R_0805_2012Metric
U8: AD831; PLCC-20
Y1: OSC25M-3.3I/S5; Oscillator_SMD_Fordahl_DFAS15-4Pin_5.0x3.2mm_HandSoldering

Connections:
+3.3V: C37.2, Y1.1 (EN), Y1.4 (Vdd); also elsewhere on the board
+10V: C28.2, C29.2, C30.2, R31.2, U8.1 (V_{P}), U8.9 (V_{P}), U8.12 (V_{P}); also elsewhere on the board
/freq_converter/AN: U8.2 (IFN), U8.3 (AN)
/freq_converter/AP: U8.19 (AP), U8.20 (IFP)
/freq_converter/IF_BPF: C32.2, L3.2, L4.1, L6.4, R34.1
/freq_converter/IF_C: C31.2, L3.1
/freq_converter/IF_MIX_OUT: R27.1, R28.1, U8.16 (OUT)
/freq_converter/IF_OUT+: J8.1, L6.1
/freq_converter/IF_OUT-: J8.2, L6.3
/freq_converter/IF_TERM: C31.1, R27.2
/freq_converter/LO_IN+: C40.1, U8.11 (LOP)
/freq_converter/LO_IN-: C42.1, U8.10 (LON)
/freq_converter/LO_L1: C39.2, L8.2
/freq_converter/LO_LPF: C39.1, C40.2, R33.1
/freq_converter/LO_OSC: R29.2, Y1.3 (OUT)
/freq_converter/MIX_AMP_BIAS: C38.2, R30.1, R31.1, R32.2, U8.18 (COM)
/freq_converter/MIX_AMP_FB: R28.2, R30.2, U8.17 (VFB)
/freq_converter/RF_CONN+: J9.1, L7.4
/freq_converter/RF_CONN-: J9.2, L7.5
/freq_converter/RF_IN+: C35.2, U8.6 (RFP)
/freq_converter/RF_IN-: C33.1, U8.7 (RFN)
/freq_converter/RF_T: C34.1, L7.1
/freq_converter/RF_Z: C34.2, C35.1, L5.1
GND: C28.1, C29.1, C30.1, C32.1, C33.2, C36.2, C37.1, C38.1, C42.2, L4.2, L5.2, L6.2, L6.5, L7.3, R32.1, R33.2, R34.2, U8.4 (GND), U8.5 (V_{N}), U8.8 (V_{N}), U8.13 (GND), U8.15 (V_{N}), Y1.2 (GND); also elsewhere on the board
unnamed: C36.1, L8.1, R29.1

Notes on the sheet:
L8: Xl = 2 PI f L L = Xl / 2 PI f L = 120ohm / (2 PI 25MHz)
2nd order chebyshev BPF fc = 70MHz, B= 10MHz
Umax +/- 1V
SW USB driver
ADC
C39: Xc = 1/2 PI f C => C = 1/2 PI f Xc C = 1/(2 PI 25MHz 120 ohm)
Imax = 20mA
USB-C
75 ohm coax
MCU

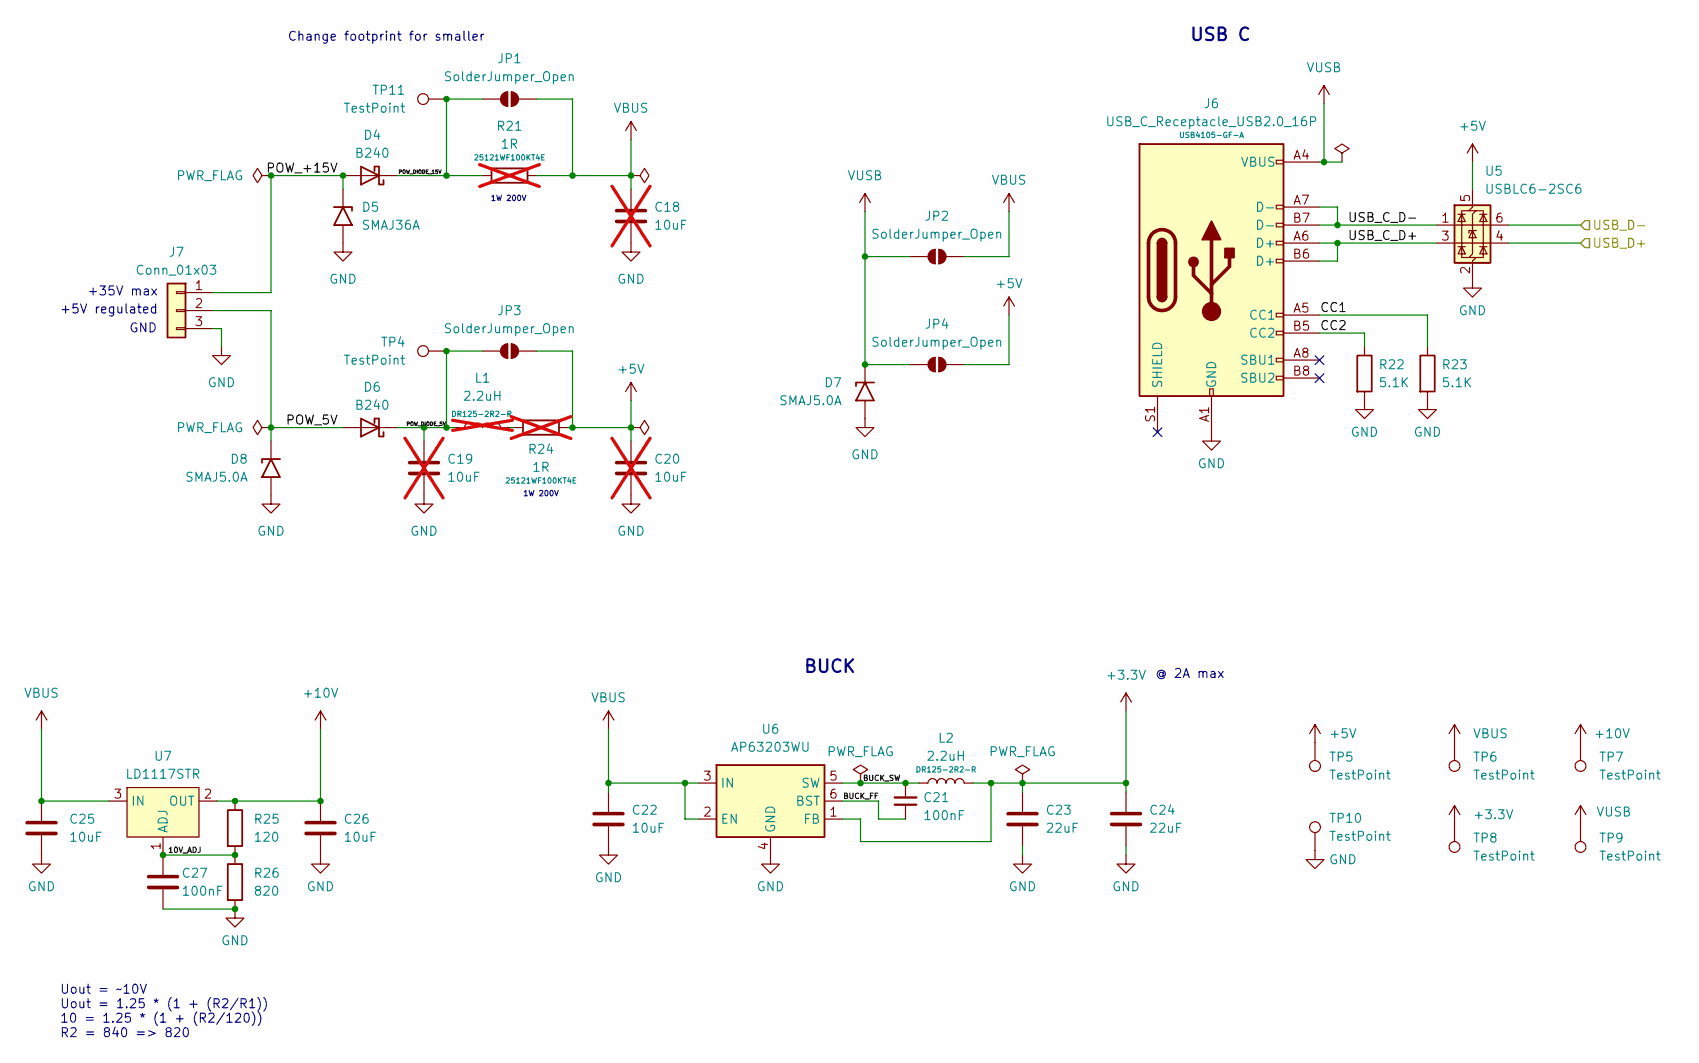
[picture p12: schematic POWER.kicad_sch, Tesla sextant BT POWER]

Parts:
C18, C19, C20: 10uF; C_0805_2012Metric; not fitted
C21, C27: 100nF; C_0805_2012Metric
C22, C25, C26: 10uF; C_0805_2012Metric
C23, C24: 22uF; C_0805_2012Metric
D4, D6: B240; D_SMB
D5: SMAJ36A; D_SMA
D7, D8: SMAJ5.0A; D_SMA
J6: USB_C_Receptacle_USB2.0_16P; USB_C_Receptacle_GCT_USB4105-xx-A_16P_TopMnt_Horizontal; Part_num USB4105-GF-A
J7: Conn_01x03; Conn_Solder_1x03_SMD
JP1, JP2, JP3, JP4: SolderJumper_Open; SolderJumper-2_P1.3mm_Open_TrianglePad1.0x1.5mm
L1: 2.2uH; L_12x12mm_H8mm; Part_num DR125-2R2-R; not fitted
L2: 2.2uH; L_12x12mm_H8mm; Part_num DR125-2R2-R
R21, R24: 1R; R_2512_6332Metric; Part_num 25121WF100KT4E; not fitted
R22, R23: 5.1K; R_0805_2012Metric
R25: 120; R_0805_2012Metric
R26: 820; R_0805_2012Metric
TP4, TP5, TP6, TP7, TP8, TP9, TP10, TP11: TestPoint; TestPoint_Pad_D2.5mm
U5: USBLC6-2SC6; SOT-23-6
U6: AP63203WU; TSOT-23-6
U7: LD1117STR; SOT-223

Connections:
+3.3V: C23.1, C24.1, L2.2, TP8.1, U6.1 (FB); also elsewhere on the board
+5V: C20.1, JP3.2 (B), JP4.2 (B), R24.1, TP5.1, U5.5 (VBUS); also elsewhere on the board
+10V: C26.1, R25.1, TP7.1, U7.2 (OUT), U7.4 (OUT); also elsewhere on the board
/POWER+USB/10V_ADJ: C27.1, R25.2, R26.1, U7.1 (ADJ)
/POWER+USB/BUCK_FF: C21.1, U6.6 (BST)
/POWER+USB/BUCK_SW: C21.2, L2.1, U6.5 (SW)
/POWER+USB/CC1: J6.A5 (CC1), R23.1
/POWER+USB/CC2: J6.B5 (CC2), R22.1
/POWER+USB/POW_5V: D6.2 (A), D8.1 (A1), J7.2
/POWER+USB/POW_+15V: D4.2 (A), D5.1 (A1), J7.1
/POWER+USB/POW_DIODE_5V: C19.1, D6.1 (K), JP3.1 (A), L1.1, TP4.1
/POWER+USB/POW_DIODE_15V: D4.1 (K), JP1.1 (A), R21.2, TP11.1
/POWER+USB/USB_C_D+: J6.A6 (D+), J6.B6 (D+), U5.3 (I/O2)
/POWER+USB/USB_C_D-: J6.A7 (D-), J6.B7 (D-), U5.1 (I/O1)
/USB_ESP_D+: U5.4 (I/O2); also elsewhere on the board
/USB_ESP_D-: U5.6 (I/O1); also elsewhere on the board
GND: C18.2, C19.2, C20.2, C22.2, C23.2, C24.2, C25.2, C26.2, C27.2, D5.2 (A2), D7.2 (A2), D8.2 (A2), J6.A1 (GND), J6.A12 (GND), J6.B1 (GND), J6.B12 (GND), J7.3, R22.2, R23.2, R26.2, TP10.1, U5.2 (GND), U6.4 (GND); also elsewhere on the board
unnamed: L1.2, R24.2
VBUS: C18.1, C22.1, C25.1, JP1.2 (B), JP2.2 (B), R21.1, TP6.1, U6.2 (EN), U6.3 (IN), U7.3 (IN)
VUSB: D7.1 (A1), J6.A4 (VBUS), J6.A9 (VBUS), J6.B4 (VBUS), J6.B9 (VBUS), JP2.1 (A), JP4.1 (A), TP9.1

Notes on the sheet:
Uout = ~10V Uout = 1.25 * (1 + (R2/R1)) 10 = 1.25 * (1 + (R2/120)) R2 = 840 => 820
@ 2A max
+5V regulated
GND
1W 200V
+35V max
Change footprint for smaller
BUCK
USB C

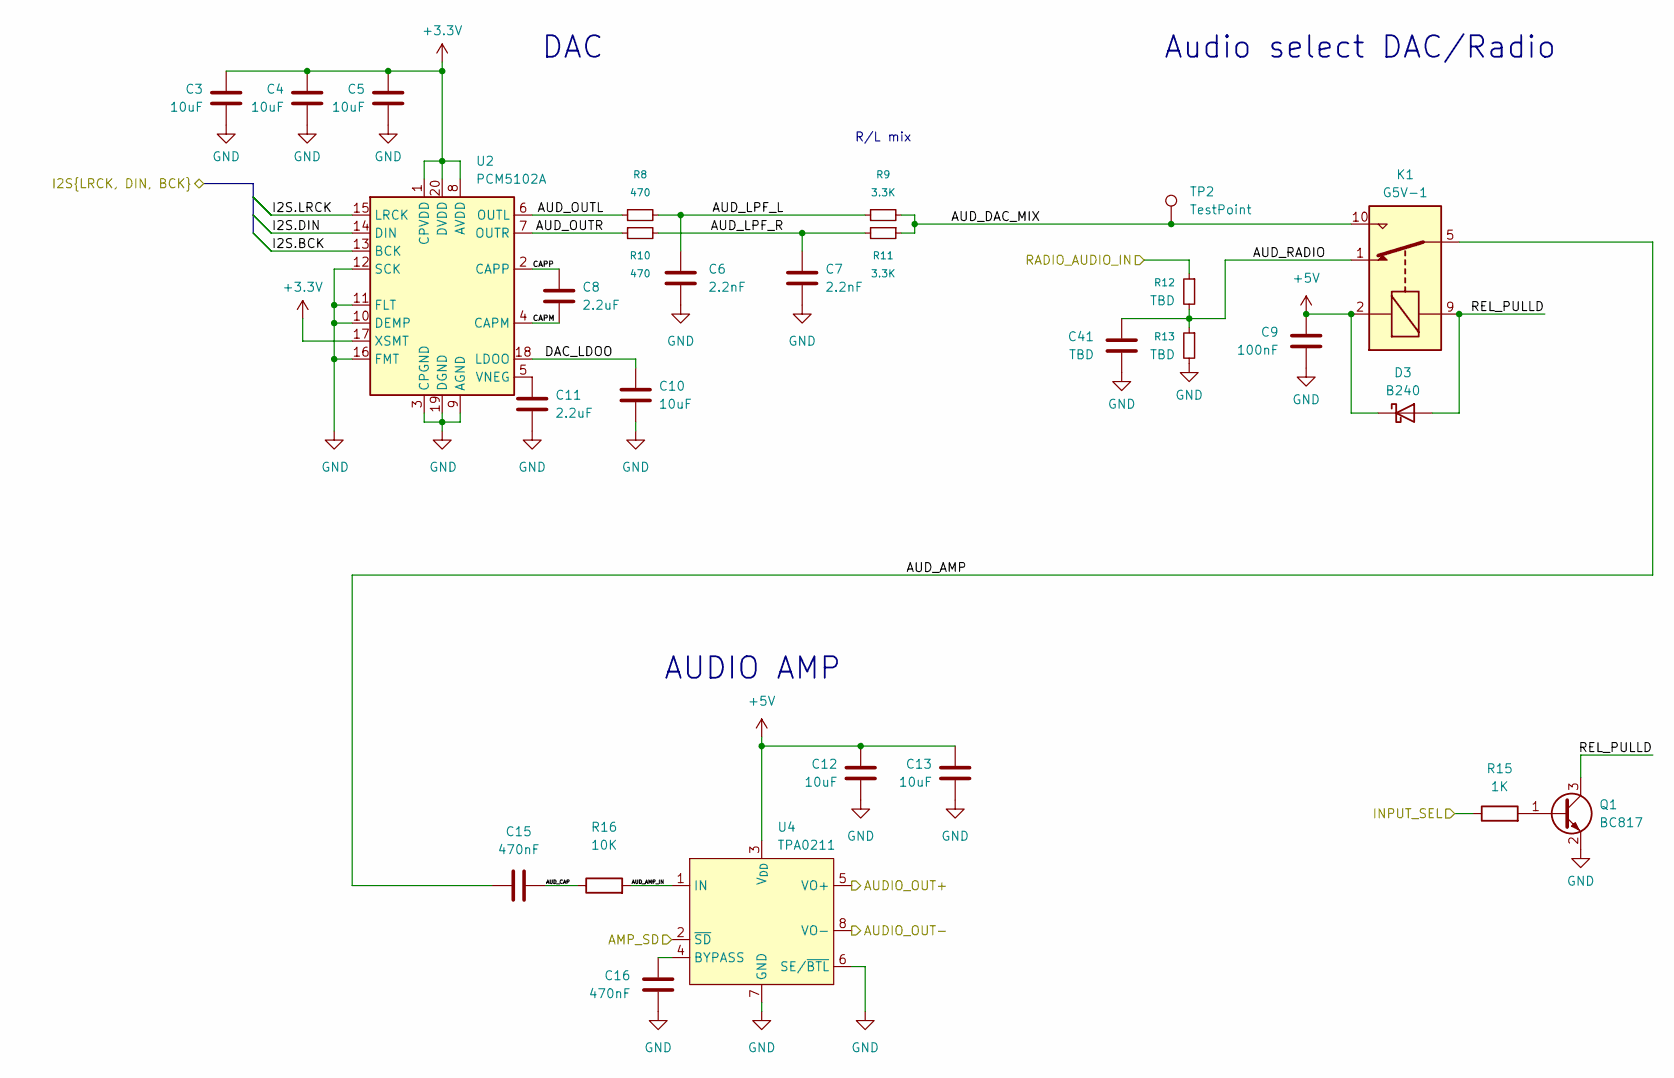
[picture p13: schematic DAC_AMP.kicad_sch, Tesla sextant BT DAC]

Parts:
C3, C4, C5, C10, C12, C13: 10uF; C_0805_2012Metric
C6, C7: 2.2nF; C_0805_2012Metric
C8, C11: 2.2uF; C_0805_2012Metric
C9: 100nF; C_0805_2012Metric
C15, C16: 470nF; C_0805_2012Metric
C41: TBD; C_0805_2012Metric
D3: B240; D_SMB
K1: G5V-1; Relay_SPDT_Omron_G5V-1
Q1: BC817; SOT-23
R8, R10: 470; R_0805_2012Metric
R9, R11: 3.3K; R_0805_2012Metric
R12, R13: TBD; R_0805_2012Metric
R15: 1K; R_0805_2012Metric
R16: 10K; R_0805_2012Metric
TP2: TestPoint; TestPoint_Pad_D2.5mm
U2: PCM5102A; TSSOP-20_4.4x6.5mm_P0.65mm
U4: TPA0211; HVSSOP-8-1EP_3x3mm_P0.65mm_EP1.57x1.89mm_ThermalVias

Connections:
+3.3V: C3.1, C4.1, C5.1, U2.1 (CPVDD), U2.8 (AVDD), U2.17 (XSMT), U2.20 (DVDD); also elsewhere on the board
+5V: C9.1, C12.1, C13.1, D3.1 (K), K1.2, U4.3 (V_{DD}); also elsewhere on the board
/AMP_SD: U4.2 (~SD); also elsewhere on the board
/AUDIO_SEL: R15.1; also elsewhere on the board
/DAC_AMP/AUDIO_OUT+: U4.5 (VO+); also elsewhere on the board
/DAC_AMP/AUDIO_OUT-: U4.8 (VO-); also elsewhere on the board
/DAC_AMP/AUD_AMP: C15.1, K1.5, K1.6
/DAC_AMP/AUD_AMP_IN: R16.2, U4.1 (IN)
/DAC_AMP/AUD_CAP: C15.2, R16.1
/DAC_AMP/AUD_DAC_MIX: K1.10, R9.2, R11.1, TP2.1
/DAC_AMP/AUD_LPF_L: C6.1, R8.2, R9.1
/DAC_AMP/AUD_LPF_R: C7.1, R10.2, R11.2
/DAC_AMP/AUD_OUTL: R8.1, U2.6 (OUTL)
/DAC_AMP/AUD_OUTR: R10.1, U2.7 (OUTR)
/DAC_AMP/AUD_RADIO: C41.1, K1.1, R12.2, R13.1
/DAC_AMP/CAPM: C8.2, U2.4 (CAPM)
/DAC_AMP/CAPP: C8.1, U2.2 (CAPP)
/DAC_AMP/DAC_LDOO: C10.1, U2.18 (LDOO)
/DAC_AMP/REL_PULLD: D3.2 (A), K1.9, Q1.3 (C)
/I2S.BCK: U2.13 (BCK); also elsewhere on the board
/I2S.DIN: U2.14 (DIN); also elsewhere on the board
/I2S.LRCK: U2.15 (LRCK); also elsewhere on the board
/RADIO_AUDIO_IN: R12.1; also elsewhere on the board
GND: C3.2, C4.2, C5.2, C6.2, C7.2, C9.2, C10.2, C11.2, C12.2, C13.2, C16.2, C41.2, Q1.2 (E), R13.2, U2.3 (CPGND), U2.9 (AGND), U2.10 (DEMP), U2.11 (FLT), U2.12 (SCK), U2.16 (FMT), U2.19 (DGND), U4.6 (SE/~BTL), U4.7 (GND); also elsewhere on the board
unnamed: Q1.1 (B), R15.2
unnamed: C11.1, U2.5 (VNEG)
unnamed: C16.1, U4.4 (BYPASS)

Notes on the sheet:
Audio select DAC/Radio
AUDIO AMP
R/L mix
DAC

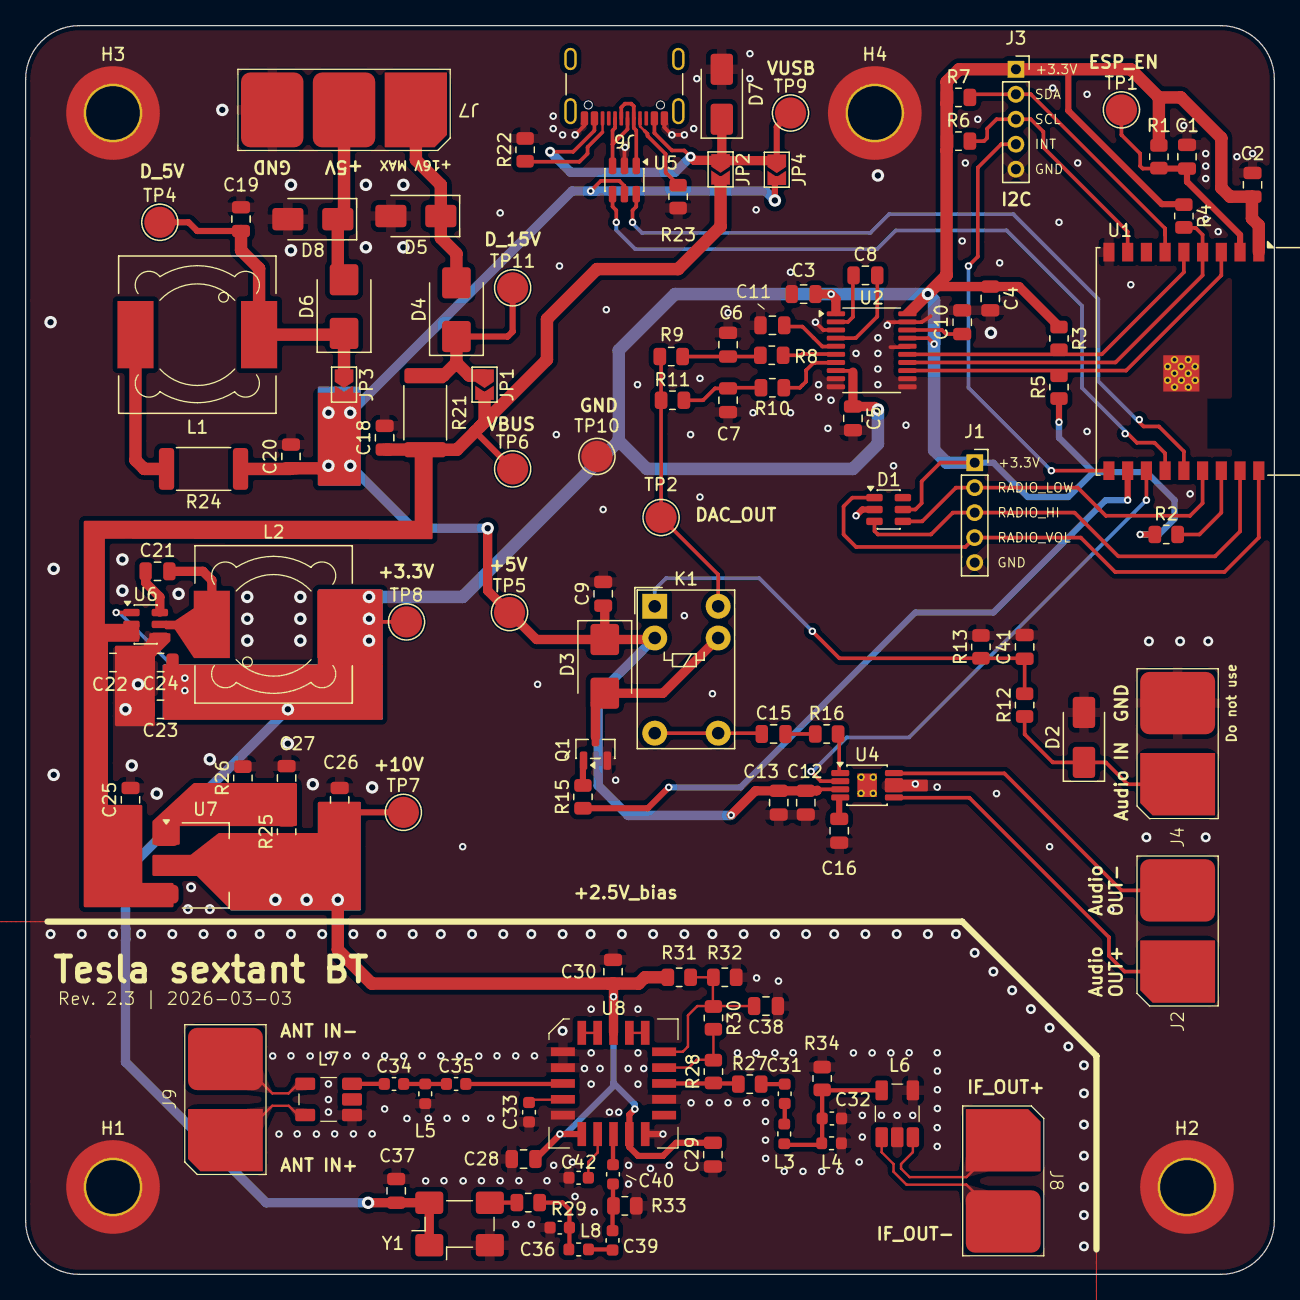
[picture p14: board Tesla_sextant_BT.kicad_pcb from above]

Board: 4 copper layers, 100.0 x 100.0 mm, 121 parts (0 on the bottom side), 74 nets.

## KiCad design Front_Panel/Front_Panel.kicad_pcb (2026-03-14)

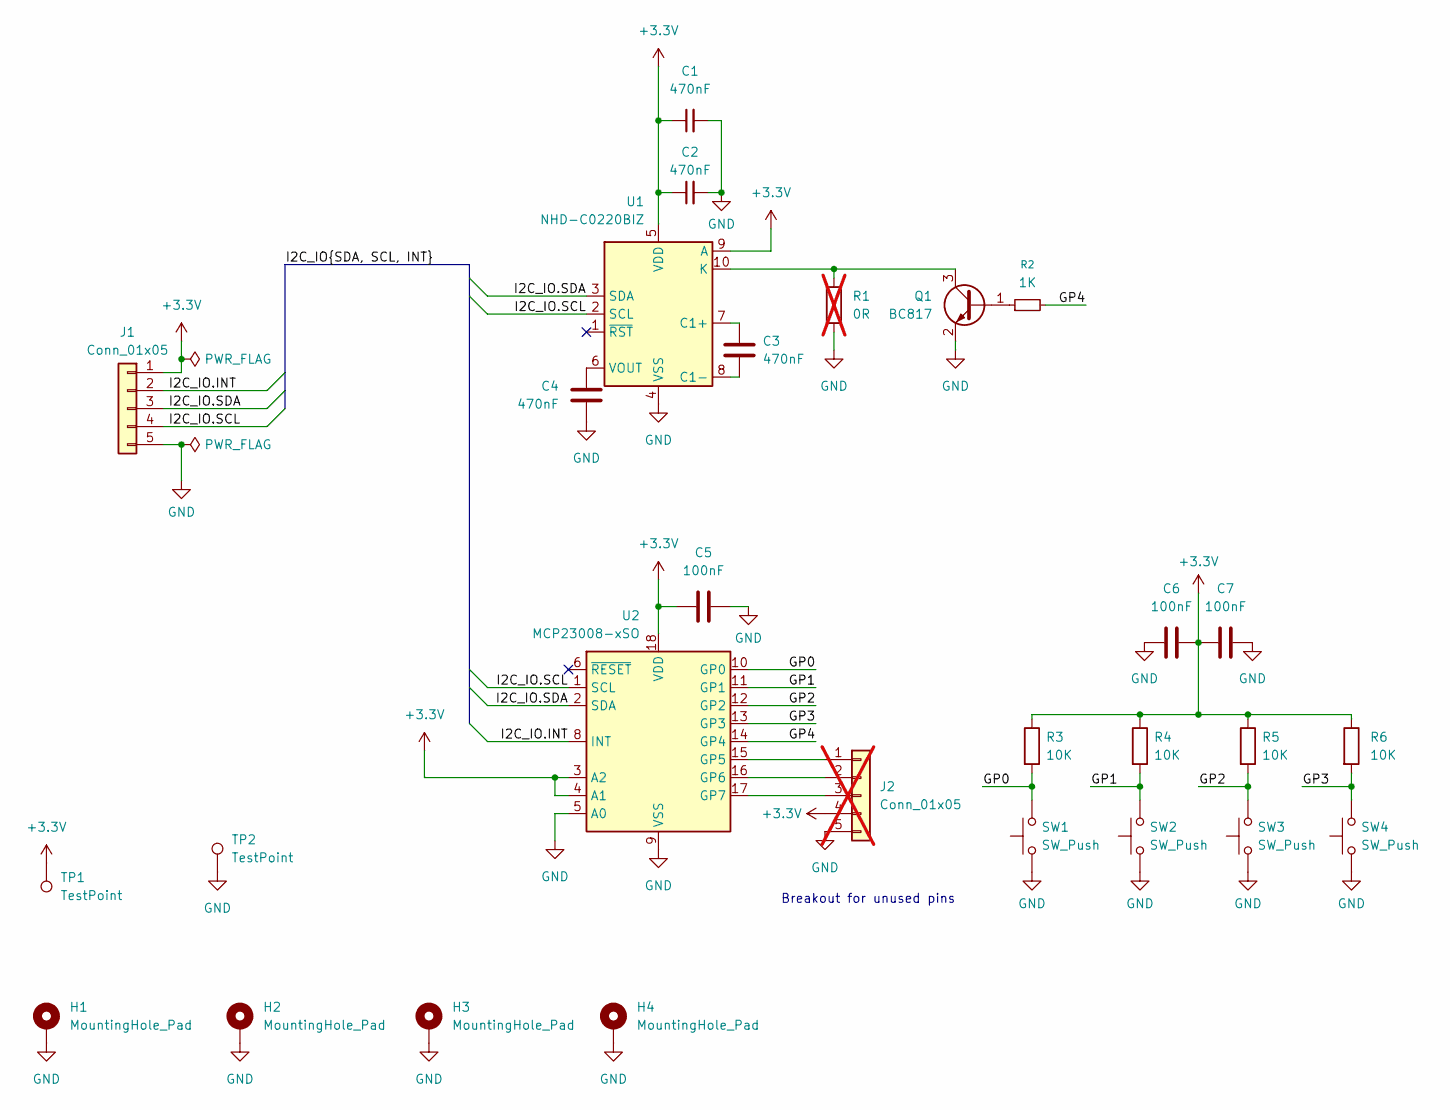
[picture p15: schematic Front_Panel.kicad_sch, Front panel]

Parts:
C1, C2, C3, C4: 470nF; C_0805_2012Metric
C5, C6, C7: 100nF; C_0805_2012Metric
H1, H2, H3, H4: MountingHole_Pad; MountingHole_4.3mm_M4_DIN965_Pad_TopBottom
J1: Conn_01x05; PinSocket_1x05_P2.00mm_Vertical
J2: Conn_01x05; PinSocket_1x05_P2.00mm_Vertical; not fitted
Q1: BC817; SOT-23
R1: 0R; R_0805_2012Metric; not fitted
R2: 1K; R_0805_2012Metric
R3, R4, R5, R6: 10K; R_0805_2012Metric
SW1, SW2, SW3, SW4: SW_Push; SW_PUSH-12mm_Wuerth-430476085716
TP1, TP2: TestPoint; TestPoint_Pad_D3.0mm
U1: NHD-C0220BIZ; NHD-C0220BiZ
U2: MCP23008-xSO; SOIC-18W_7.5x11.6mm_P1.27mm

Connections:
+3.3V: C1.1, C2.1, C5.1, C6.2, C7.1, J1.1, J2.4, R3.1, R4.1, R5.1, R6.1, TP1.1, U1.5 (VDD), U1.9 (A), U2.3 (A2), U2.4 (A1), U2.18 (VDD)
/GP0: R3.2, SW1.2, U2.10 (GP0)
/GP1: R4.2, SW2.2, U2.11 (GP1)
/GP2: R5.2, SW3.2, U2.12 (GP2)
/GP3: R6.2, SW4.2, U2.13 (GP3)
/GP4: R2.2, U2.14 (GP4)
/I2C_IO.INT: J1.2, U2.8 (INT)
/I2C_IO.SCL: J1.4, U1.2 (SCL), U2.1 (SCL)
/I2C_IO.SDA: J1.3, U1.3 (SDA), U2.2 (SDA)
GND: C1.2, C2.2, C4.2, C5.2, C6.1, C7.2, H1.1, H2.1, H3.1, H4.1, J1.5, J2.5, Q1.2 (E), R1.2, SW1.1, SW2.1, SW3.1, SW4.1, TP2.1, U1.4 (VSS), U2.5 (A0), U2.9 (VSS)
unnamed: J2.1, U2.15 (GP5)
unnamed: J2.2, U2.16 (GP6)
unnamed: J2.3, U2.17 (GP7)
unnamed: Q1.1 (B), R2.1
unnamed: Q1.3 (C), R1.1, U1.10 (K)
unnamed: C3.1, U1.7 (C1+)
unnamed: C3.2, U1.8 (C1-)
unnamed: C4.1, U1.6 (VOUT)

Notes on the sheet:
Breakout for unused pins

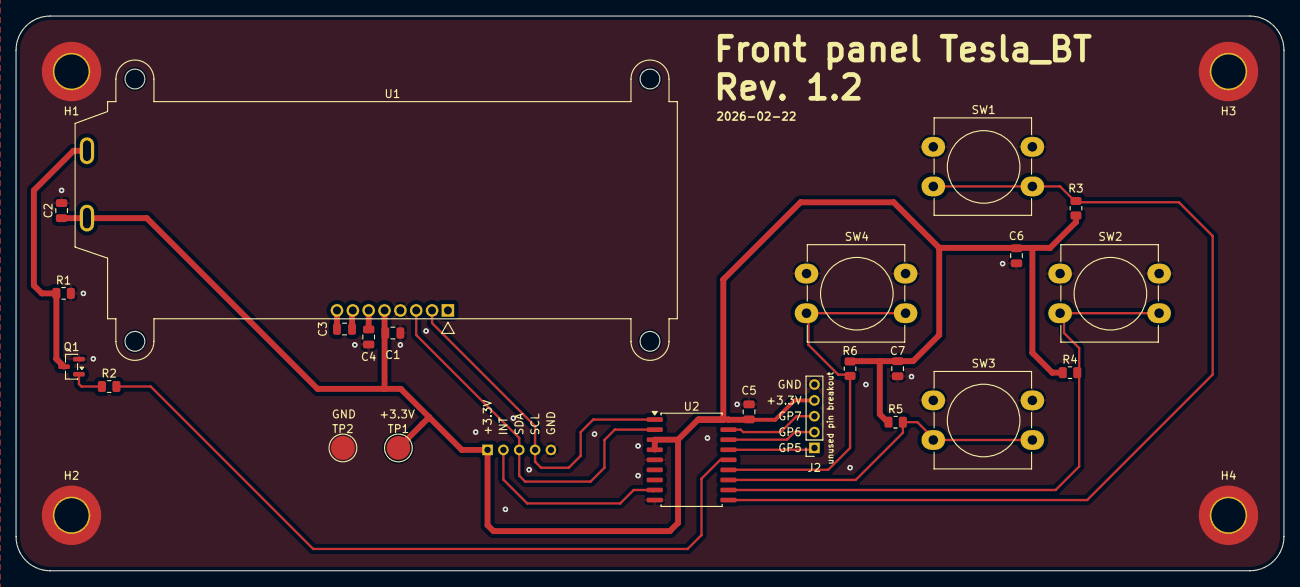
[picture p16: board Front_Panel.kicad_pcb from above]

Board: 2 copper layers, 160.0 x 70.0 mm, 28 parts (1 on the bottom side), 18 nets.

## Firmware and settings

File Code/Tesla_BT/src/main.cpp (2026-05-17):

#include <Arduino.h>

/*
 * ESP32-C3-WROOM-02 Bluetooth A2DP přijímač
 *
 * Závislosti (nainstaluj přes Library Manager):
 *   - ESP32-A2DP by Phil Schatzmann (https://github.com/pschatzmann/ESP32-A2DP)
 *   - LiquidCrystal_I2C (nebo HD44780 I2C dle tvého LCD modulu)
 *
 * Board: ESP32C3 Dev Module
 *
 * Piny dle schématu:
 *   I2S_BCK   = IO3
 *   I2S_DIN   = IO4   (DATA OUT do DAC/zesilovače)
 *   I2S_LRCK  = IO5
 *   I2C_SDA   = IO6
 *   I2C_SCL   = IO8
 *   RADIO_VOL = IO18  (ADC - hlasitost)
 *   RADIO_HI  = IO17  (ADC - výšky / treble)
 *   RADIO_LOW = IO15  (ADC - basy / bass)
 *   IO2       = IO16  (ADC - volný / balance nebo jiný parametr)
 *   AUDIO_SEL = IO11  (digitální výstup - výběr zdroje audia)
 *   AMP_SD    = IO12  (digitální výstup - shutdown zesilovače, HIGH = zapnuto)
 */

#include "BluetoothA2DPSink.h"
#include <Wire.h>
#include <LiquidCrystal_I2C.h>

// ── Piny ────────────────────────────────────────────────────────────────────
#define I2S_BCK_PIN 3
#define I2S_DATA_PIN 4
#define I2S_LRCK_PIN 5

#define I2C_SDA_PIN 6
#define I2C_SCL_PIN 8

#define PIN_VOL 18     // ADC – hlasitost
#define PIN_TREBLE 17  // ADC – výšky
#define PIN_BASS 15    // ADC – basy
#define PIN_BALANCE 16 // ADC – balance (IO2 ve schématu)

#define PIN_AUDIO_SEL 11 // HIGH = Bluetooth vstup vybrán
#define PIN_AMP_SD 12    // HIGH = zesilovač aktivní, LOW = shutdown

// ── LCD (I2C adresa typicky 0x27 nebo 0x3F, 16x2) ──────────────────────────
LiquidCrystal_I2C lcd(0x27, 16, 2);

// ── A2DP ────────────────────────────────────────────────────────────────────
BluetoothA2DPSink a2dp_sink;

// ── Globální stav ────────────────────────────────────────────────────────────
String bt_device_name = "";
String bt_track_artist = "";
String bt_track_title = "";
bool connected = false;

int vol_raw = 0;         // 0–4095
uint8_t volume_pct = 80; // 0–100

unsigned long last_adc_read = 0;
unsigned long last_lcd_update = 0;
const unsigned long ADC_INTERVAL = 80;  // ms
const unsigned long LCD_INTERVAL = 500; // ms

// ── Callback: spojení / odpojení ─────────────────────────────────────────────
void on_connection_state_changed(esp_a2d_connection_state_t state, void *)
{
  if (state == ESP_A2D_CONNECTION_STATE_CONNECTED)
  {
    connected = true;
    // Zapni zesilovač
    digitalWrite(PIN_AMP_SD, HIGH);
    Serial.println("[BT] Připojeno");
  }
  else if (state == ESP_A2D_CONNECTION_STATE_DISCONNECTED)
  {
    connected = false;
    bt_device_name = "";
    bt_track_artist = "";
    bt_track_title = "";
    // Ztlum zesilovač při odpojení
    digitalWrite(PIN_AMP_SD, LOW);
    Serial.println("[BT] Odpojeno");
  }
}

// ── Callback: AVRCP metadata (název skladby, interpret) ──────────────────────
void avrc_metadata_callback(uint8_t id, const uint8_t *text)
{
  String s = String((char *)text);
  switch (id)
  {
  case ESP_AVRC_MD_ATTR_TITLE:
    bt_track_title = s;
    Serial.print("[META] Název: ");
    Serial.println(s);
    break;
  case ESP_AVRC_MD_ATTR_ARTIST:
    bt_track_artist = s;
    Serial.print("[META] Interpret: ");
    Serial.println(s);
    break;
  default:
    break;
  }
}

// ── Přečti ADC a aktualizuj hlasitost ────────────────────────────────────────
void read_adc()
{
  vol_raw = analogRead(PIN_VOL); // 0–4095
  int treble = analogRead(PIN_TREBLE);
  int bass = analogRead(PIN_BASS);
  // int balance = analogRead(PIN_BALANCE); // případné využití

  // Mapuj hlasitost 0–100
  volume_pct = map(vol_raw, 0, 4095, 0, 100);

  // Nastav hlasitost A2DP (0–127)
  uint8_t a2dp_vol = map(volume_pct, 0, 100, 0, 127);
  a2dp_sink.set_volume(a2dp_vol);

  // Servisní výpis pro ladění
  Serial.printf("[ADC] VOL=%d%% | TREBLE=%d | BASS=%d\n",
                volume_pct, treble, bass);
}

// ── Obnov LCD ────────────────────────────────────────────────────────────────
void update_lcd()
{
  lcd.clear();

  if (!connected)
  {
    // Hledáme zařízení
    lcd.setCursor(0, 0);
    lcd.print("BT Radio");
    lcd.setCursor(0, 1);
    lcd.print("Ceka na spojeni.");
    return;
  }

  // Řádek 0: interpret (max 16 znaků)
  String artist = bt_track_artist.length() > 0 ? bt_track_artist : "Neznamy";
  if (artist.length() > 16)
    artist = artist.substring(0, 16);
  lcd.setCursor(0, 0);
  lcd.print(artist);

  // Řádek 1: název skladby + hlasitost
  String title = bt_track_title.length() > 0 ? bt_track_title : "---";
  if (title.length() > 12)
    title = title.substring(0, 12);
  String line2 = title;
  // Doplň hlasitost vpravo (formát "xxx%")
  String vol_str = String(volume_pct) + "%";
  while ((line2.length() + vol_str.length()) < 16)
    line2 += " ";
  line2 += vol_str;
  lcd.setCursor(0, 1);
  lcd.print(line2);
}

// ── Setup ────────────────────────────────────────────────────────────────────
void setup()
{
  Serial.begin(115200);
  Serial.println("\n[BOOT] ESP32-C3 BT Radio");

  // Digitální výstupy
  pinMode(PIN_AUDIO_SEL, OUTPUT);
  pinMode(PIN_AMP_SD, OUTPUT);
  digitalWrite(PIN_AUDIO_SEL, HIGH); // Vyber Bluetooth vstup
  digitalWrite(PIN_AMP_SD, LOW);     // Zesilovač zatím vypnut

  // ADC vstupy (výchozí, není třeba pinMode pro analogRead)
  // Volitelně nastav atenuaci pro rozsah 0–3,3 V
  analogSetAttenuation(ADC_11db);

  // I2C + LCD
  Wire.begin(I2C_SDA_PIN, I2C_SCL_PIN);
  lcd.init();
  lcd.backlight();
  lcd.clear();
  lcd.setCursor(0, 0);
  lcd.print("BT Radio");
  lcd.setCursor(0, 1);
  lcd.print("Inicializace...");

  // I2S konfigurace pro A2DP
  i2s_pin_config_t pin_cfg = {
      .mck_io_num = I2S_PIN_NO_CHANGE,
      .bck_io_num = I2S_BCK_PIN,
      .ws_io_num = I2S_LRCK_PIN,
      .data_out_num = I2S_DATA_PIN,
      .data_in_num = I2S_PIN_NO_CHANGE};
  a2dp_sink.set_pin_config(pin_cfg);

  // Callbacks
  a2dp_sink.set_on_connection_state_changed(on_connection_state_changed);
  a2dp_sink.set_avrc_metadata_callback(avrc_metadata_callback);

  // Spusť Bluetooth – název viditelný pro telefon
  a2dp_sink.start("ESP32 Radio");

  Serial.println("[BT] Bluetooth spusten, ceka na spojeni...");
}

// ── Loop ─────────────────────────────────────────────────────────────────────
void loop()
{
  unsigned long now = millis();

  if (now - last_adc_read >= ADC_INTERVAL)
  {
    last_adc_read = now;
    read_adc();
  }

  if (now - last_lcd_update >= LCD_INTERVAL)
  {
    last_lcd_update = now;
    update_lcd();
  }
}

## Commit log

2025-11-29 updated pdf to match current schematic
2025-11-30 Netclasses, part Nums, LPF adjust
    [DAC_AMP.kicad_sch, IO_PANEL.kicad_sch, MCU.kicad_sch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]
2025-11-30 Update link text for schematic in README
2026-02-22 changes with BOM, minor fixes
    [Front_Panel-B_Cu.gbl, Front_Panel-B_Mask.gbs, Front_Panel-B_Paste.gbp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]
2026-03-13 added step files
    [Front_Panel.step, Front_Panel_simple.step, Tesla_sextant_BT.step]
2026-03-14 Board ready for manufacturing, no more changes to either KiCad projects
    [2026-03-01T104740.xlsx, DAC_AMP.kicad_sch, DIGIKEY_CONCEPT_2026-03-08T171632.csv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]
2026-03-14 Added interactive BOM link
2026-05-17 Final Project Commit
    [2026-03-01T104740.xlsx, DAC_AMP.kicad_sch, Digi-Key_Order.csv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]
